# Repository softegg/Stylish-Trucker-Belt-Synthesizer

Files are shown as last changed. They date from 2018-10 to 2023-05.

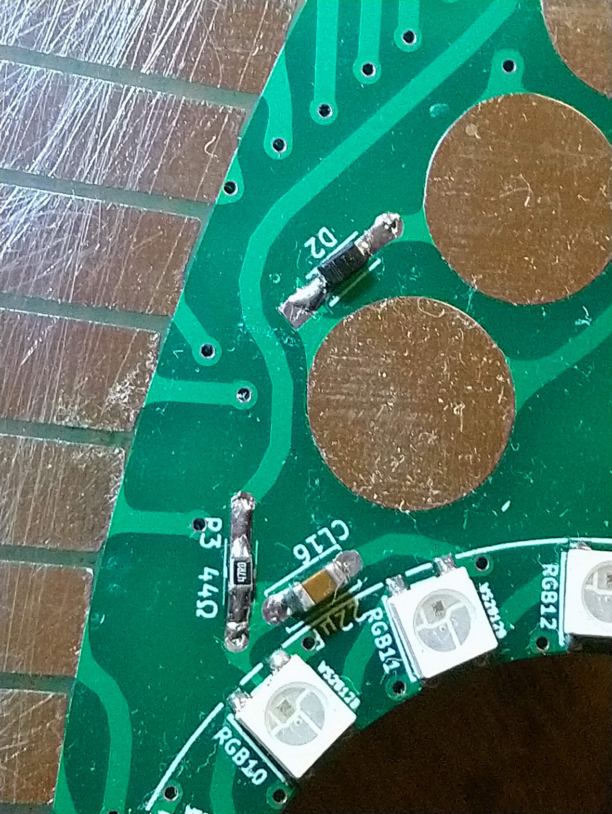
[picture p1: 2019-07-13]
photos/Stylish V4 PCB Assembled LED ring RC + diode detail front.jpg

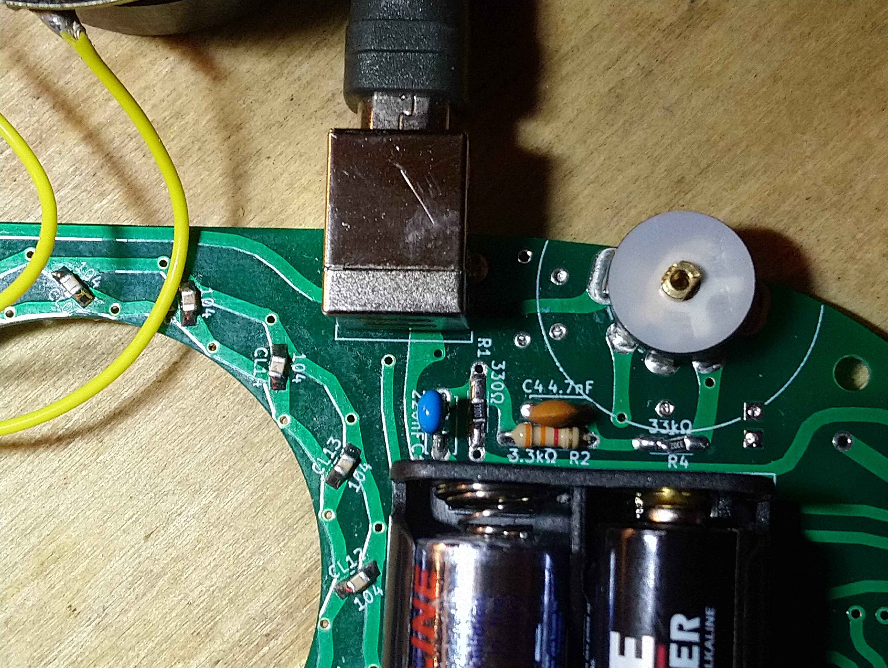
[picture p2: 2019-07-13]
photos/Stylish V4 PCB Assembled Power + PWM detail back.jpg

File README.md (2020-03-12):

# Stylish-Trucker-Belt-Synthesizer
A stylus-based music synthesizer you can wear as a belt! 

Conceived as a piece of premium swag for the MAGwest convention, "Stylish!" investigates how cheaply one can make a real, useful monophonic, digital (virtual analog) music synthesizer! Borrowing the stylus-based keyboard from the venerable Stylophone, and adding complete synthesis features like multiple oscillators, filters, envelopes, vibrato, etc. that are fully adjustable so that you can make your own sounds! It may even end up with a step sequencer and drum loop! 
Let's bring real music synthesis to the masses, stylishly!

Project is based around the "Blue Pill" STM32F103C8T6 microcontroller board that can be obtained from AliExpress for less than $2.

Code is written using Arduino IDE and STM32Duino.

Audio output is via PWM (10k resistor + 1uF capacitor) using the Mozzi library. CC4.0 Share Alike Non-commercial license applies.

LEDs are WS2812B, and the project PCB includes a header to use a standard 16 LED ring.

Amplifier is XH-M125 based on the XPT8871, which you an also buy cheaply from AliExpress. Headers are included to simply mount this board on the unit if you don't want to solder all of those parts.

Speaker is 40-50mm 0.5W 8 Ohm

<br />This work is licensed under a <a rel="license" href="http://creativecommons.org/licenses/by-nc-sa/4.0/">Creative Commons Attribution-NonCommercial-ShareAlike 4.0 International License</a>.

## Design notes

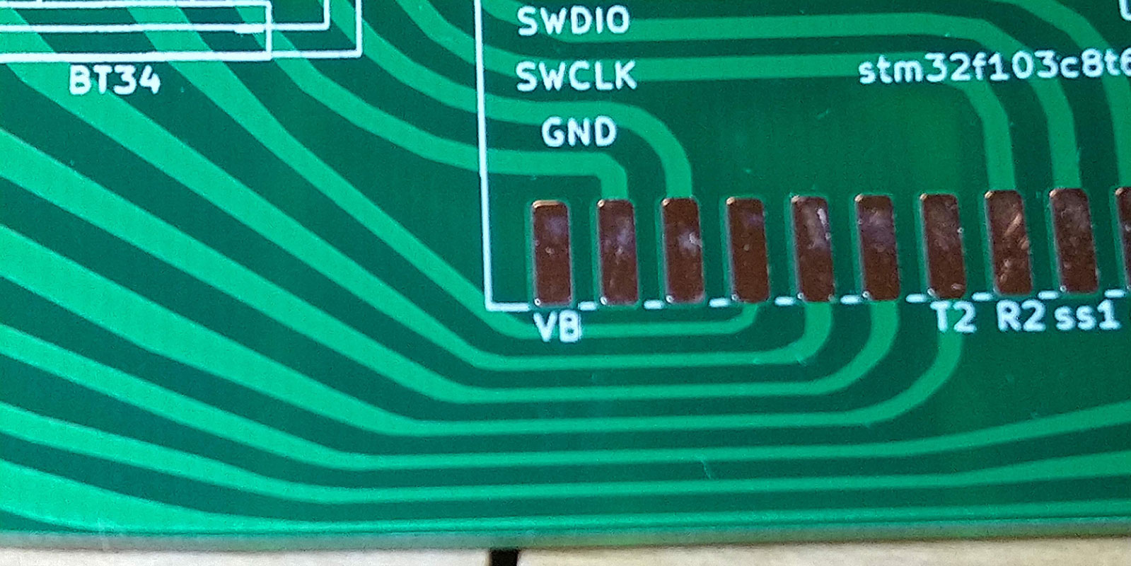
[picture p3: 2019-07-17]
photos/Thin-Trace-2.jpg

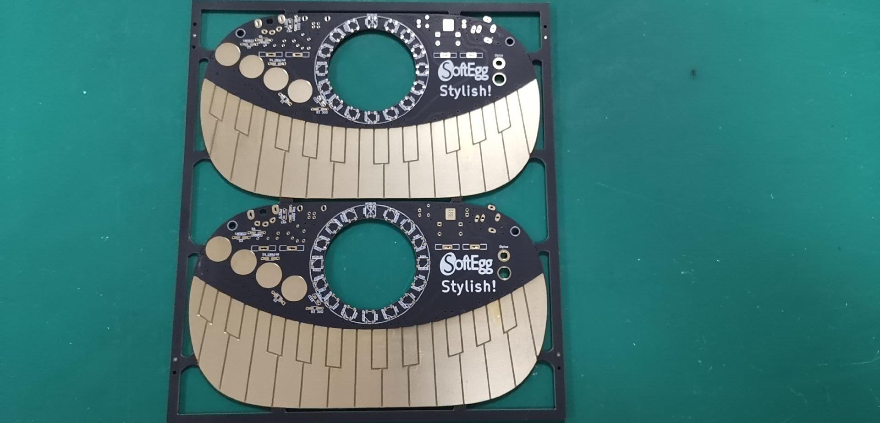
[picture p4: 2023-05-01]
photos/PCBs from Ai Green 1.jpg

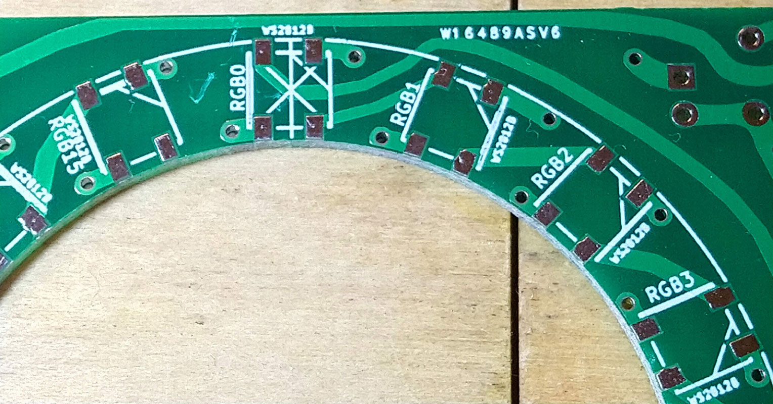
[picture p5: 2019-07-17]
photos/Thin-Trace-1.jpg

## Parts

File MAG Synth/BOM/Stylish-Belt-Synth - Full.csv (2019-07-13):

Stylish! Trucker Belt Buckle Synthesizer
Version 4.1
Bill of Materials
Designator | Package | Quantity | Designation | Supplier and ref | Notes | Changed
R4 | SMD 0805 | 1 | 33k? | https://www.aliexpress.com/item/32668040347.html
C4 | SMD 0805 | 1 | 4.7nF 472 | https://www.aliexpress.com/item/32964553793.html
CL16 | SMD 0805 | 1 | 22µF 226 | https://www.aliexpress.com/item/32964553793.html
RV1 | Wheel_Pot_W_Switch_RV12_B103_FUSTAR | 1 | Volume | https://www.aliexpress.com/item/32998159760.html | 10k? volume wheel potentiometer
BT34H1, BT12H1 | BatteryHolder_Keystone_2462_2xAA_MOD | 2 | Battery | https://www.aliexpress.com/item/32858688098.html
CA2, CA3 | SMD 0805 | 1 | 1?F 105 | https://www.aliexpress.com/item/32964553793.html
CA1 | CP_Radial_Tantal_D4.5mm_P2.50mm | 1 | 220?F
D1, D2 | SMD 0805 SOD-123 | 2 | 1N4148 | https://www.aliexpress.com/item/32897041428.html | Select 1n4148 SOD-123 See line on silk screen or arrow in copper for orientation.
D3, D4 | SMD 0805 | 2 | 1N5822 | https://www.aliexpress.com/item/32854160797.html | Select 1n5822 SS34. See line on silk screen or arrow in copper for orientation.
J1 | Stereo_Jack_3.5mm_Switch_Ledino_KB3SPRS | 1 | Headphone | https://www.aliexpress.com/item/32801912481.html
RGB0, RGB11, RGB12, RGB13, RGB14, RGB15, RGB9, RGB8, RGB7, RGB6, RGB10, RGB4, RGB3, RGB2, RGB1, RGB5 | WS2812B | 16 | WS2812B | https://www.aliexpress.com/item/32776703442.html | Very heat sensitive. Please follow heating profile on datasheet: http://www.world-semi.com/DownLoadFile/108
RA1 | SMD 0805 | 1 | 100? | https://www.aliexpress.com/item/32865947306.html
C3 | CP_Radial_D10.0mm_P5.00mm | 1 | 470?F | https://www.aliexpress.com/item/32676146418.html | Electrolytic thru hole capacitor
C2 | CP_Radial_D10.0mm_P5.00mm | 1 | 1000?F | https://www.aliexpress.com/item/1948624868.html | Electrolytic thru hole capacitor
LS1 | 4 Ohm 3W Loudspeaker 52MM | 1 | Speaker | https://www.aliexpress.com/item/32710566874.html | Speaker will mount in center hole. Leads should be long enough to reach and leave some slack. | July 12th, 2019
CA4 | SMD 0805 | 1 | 0.39?F 394 | https://www.aliexpress.com/item/32943505729.html
C1 | SMD 0805 | 1 | 220nF 224 | https://www.aliexpress.com/item/32998503996.html | Couldn’t find an 805, but 1206 will still fit.
CL15, CL14, CL13, CL12, CL11, CL10, CL9, CL8, CL7, CL6, CL5, CL4, CL3, CL2, CL1, CL0 | SMD805 | 16 | 0.1µF 104 | https://www.aliexpress.com/item/1115774532.html
R2 | SMD 0805 | 1 | 3.3k? | https://www.aliexpress.com/item/32865947306.html
R1 | SMD 0805 | 1 | 330? | https://www.aliexpress.com/item/32865947306.html
R3 | SMD 0805 | 1 | 30? | https://www.aliexpress.com/item/32865947306.html | Lowered to improve LED blue and green color. | July 13th, 2019
U1 | stm32f103c8t6-module-china-smd | 1 | stm32f103c8t6-module-china | https://www.aliexpress.com/item/STM32F103C8T6-ARM-STM32-Minimum-Development-Board-Module-for-arduino/32809970602.html | I implemented as 2 pin female pin headers and used the pinheaders that come with the controller.
U1 | Pin_Header_Angle_1x020_Pitch2.54mm_female | 2 | stm32f103c8t6-module-china | https://www.aliexpress.com/item/32733362388.html | Female pin headers for above. Be sure spacing is compatible when soldering.
U2 | SOIC-8-N | 1 | XPT8871 | https://www.aliexpress.com/item/50PCS-XPT8871-8871-SOP8/32918584881.html
J0 | USB_B | 1 | USB_B | https://www.aliexpress.com/item/539692317.html
Stylus | Stylus | 1 | Stylus | https://www.aliexpress.com/item/32959674689.html | Sold 2 per set, need 1 per unit.
Belt Clip | Belt Clip | 2 | Belt Clip | https://www.aliexpress.com/item/32991844720.html | Need these to attach to the case. Can we please ship these with the PCB order?

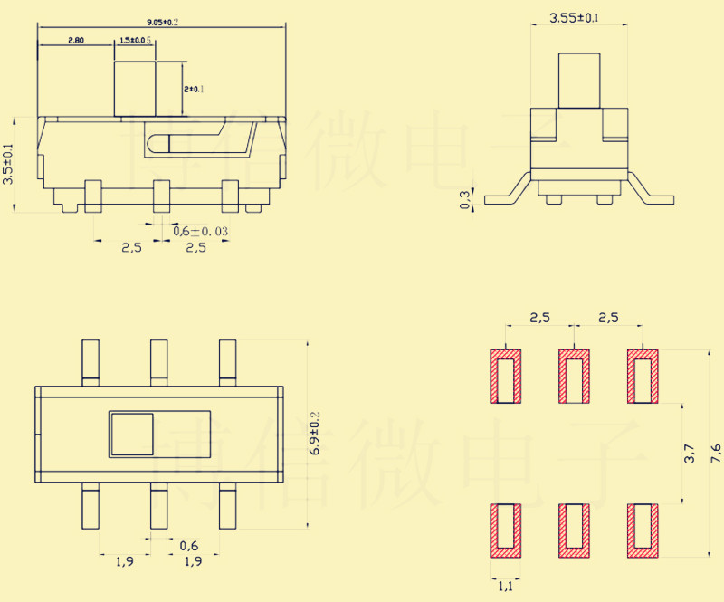
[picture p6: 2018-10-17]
3d models/Parts/MSS22D18.jpg

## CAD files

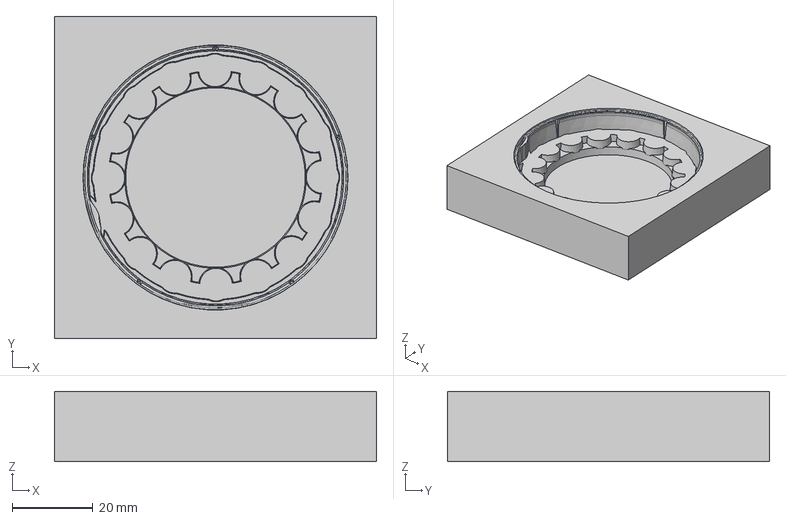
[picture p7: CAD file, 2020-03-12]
3d models/Mold/Negative/STEP/Stylish Belt Synth - LED Bezel - Outside Negative.step
80.0 x 80.0 x 17.5 mm

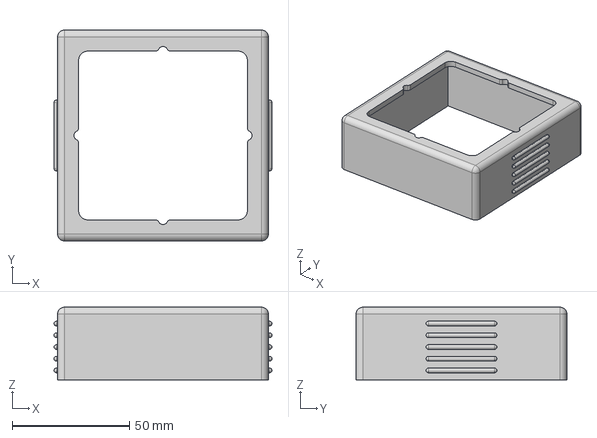
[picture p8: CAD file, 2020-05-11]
3d models/Mold/Positive - Mold Molds/STEP/Stylish Belt Synth - LED Bezel - Mold Walls.step
93.0 x 90.0 x 31.0 mm

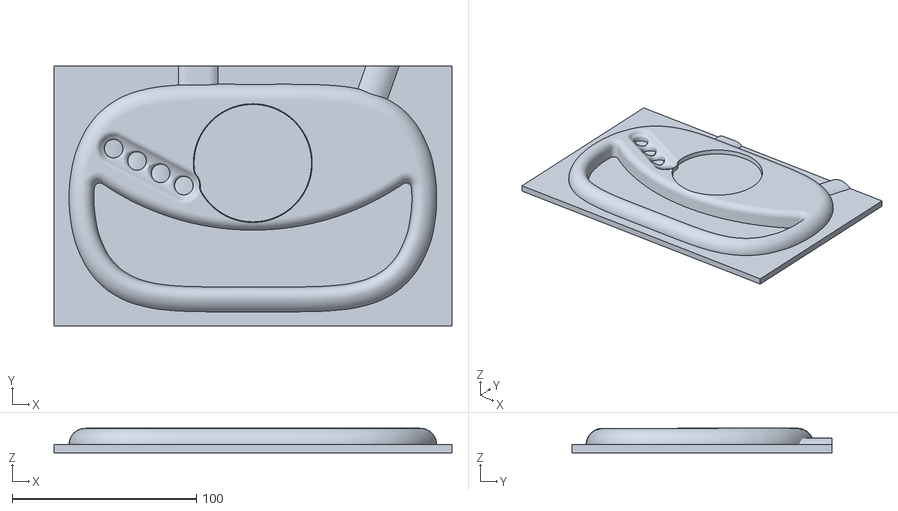
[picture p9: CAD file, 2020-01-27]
3d models/Mold/Positive - Mold Molds/STL/Stylish - Top - Outside Positive.stl
216.3 x 141.5 x 13.4

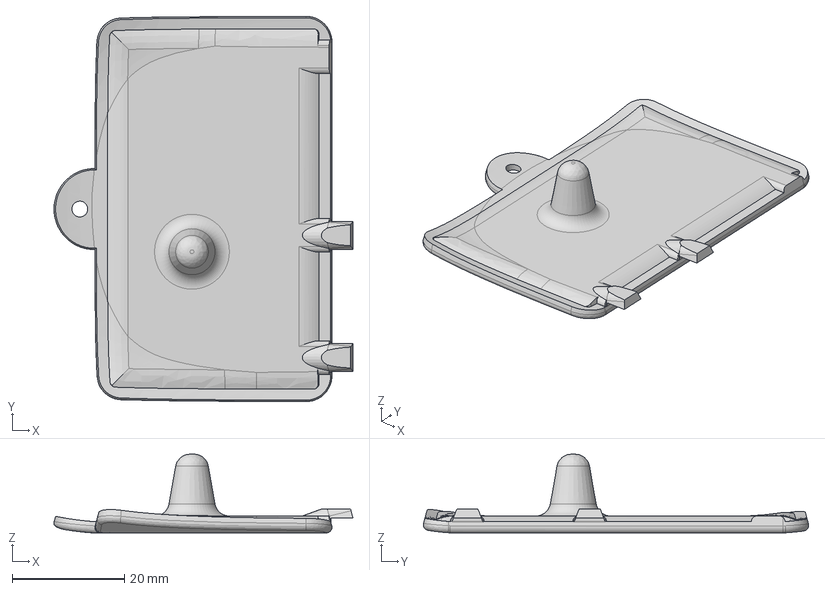
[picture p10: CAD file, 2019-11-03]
3d models/Normal Models/STEP/Stylish Belt Synth V4 Battery Door 2.step
53.2 x 68.5 x 14.0 mm

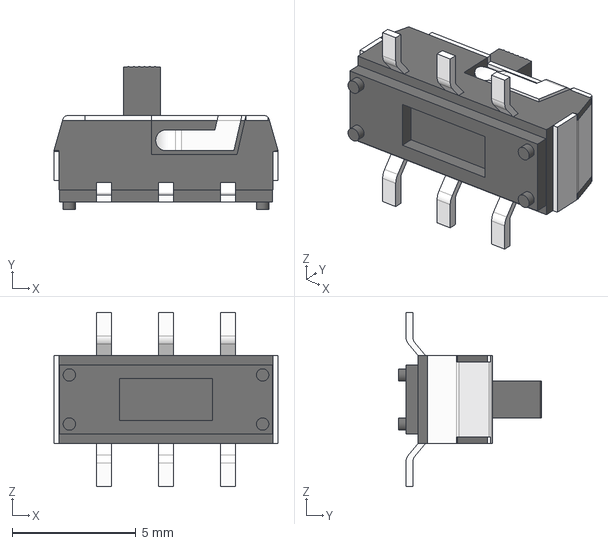
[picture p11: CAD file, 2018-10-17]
3d models/Parts/MSS22D18 Switch v3.step
9.05 x 5.79 x 7.05 mm

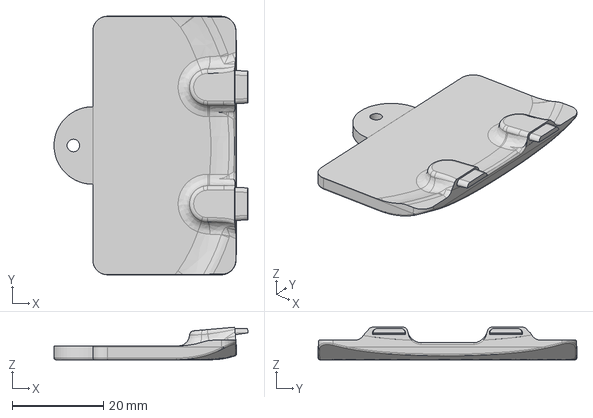
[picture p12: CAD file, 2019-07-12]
3d models/Stylish Belt Synth V2 Right Battery Door.step
42.5 x 56.7 x 7.16 mm

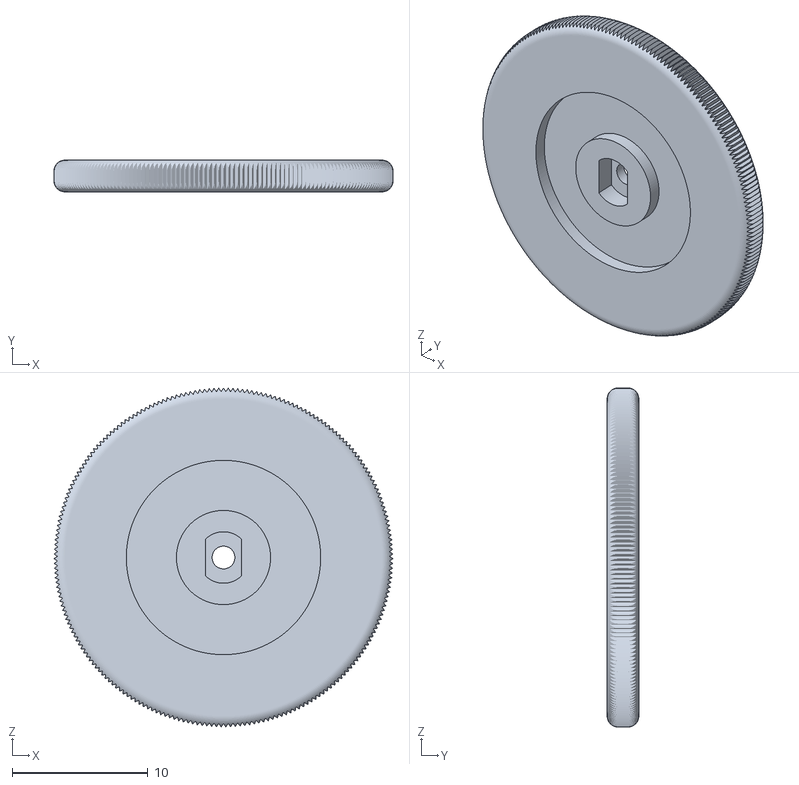
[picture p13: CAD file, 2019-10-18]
3d models/woodCNC/StylishVolumeWheelforWoodCNC (3d print this).stl
25.0 x 2.34 x 25.0

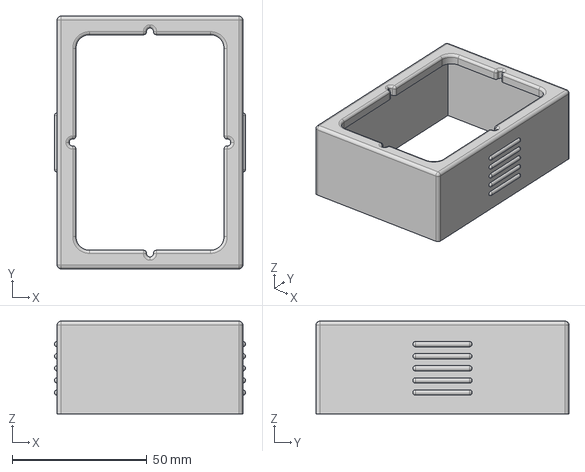
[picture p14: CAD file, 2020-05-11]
3d models/Mold/Positive - Mold Molds/STEP/Stylish Belt Synth - Battery Doors - Outside Positive Walls.step
71.0 x 94.0 x 34.5 mm

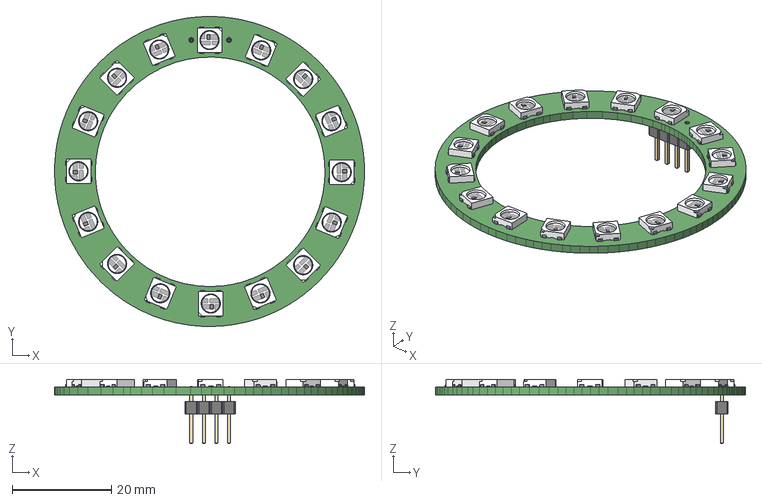
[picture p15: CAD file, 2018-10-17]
3d models/Parts/WS2812B-16_LED-RING-flip.step
62.6 x 62.6 x 13.0 mm

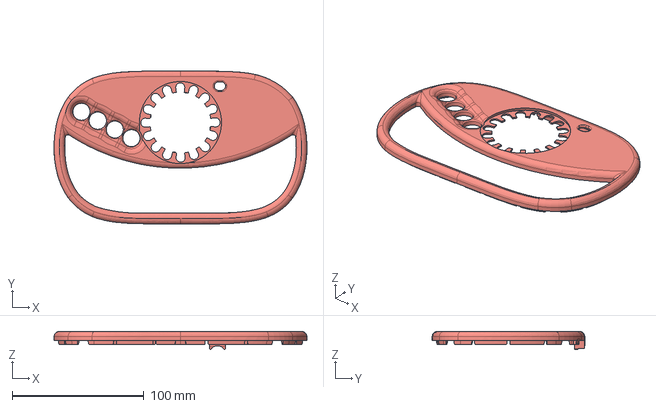
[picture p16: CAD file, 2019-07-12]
3d models/Stylish Belt Synth V2 Top.step
192.1 x 116.0 x 13.8 mm

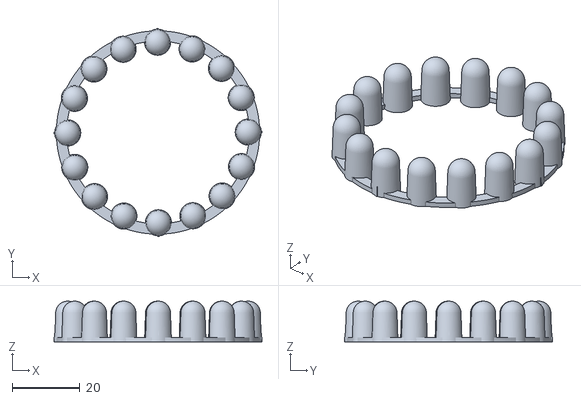
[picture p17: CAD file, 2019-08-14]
3d models/woodCNC/StylishLEDLightpipeForWoodCNC (3d print this).stl
61.3 x 61.3 x 12.0

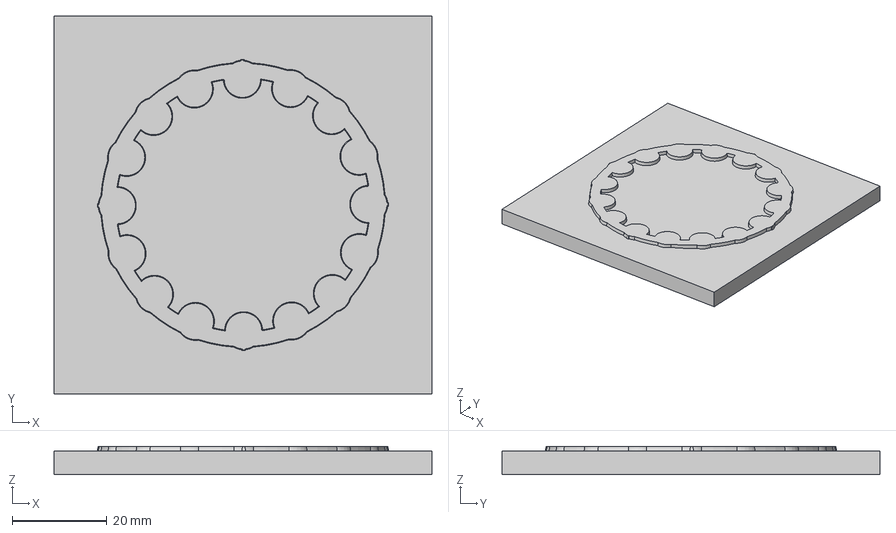
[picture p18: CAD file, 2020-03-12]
3d models/Mold/Negative/STEP/Stylish Belt Synth - LED Lightpipe - Inside Negative.step
80.0 x 80.0 x 6.00 mm
LED Bezel
LED Lightpipe

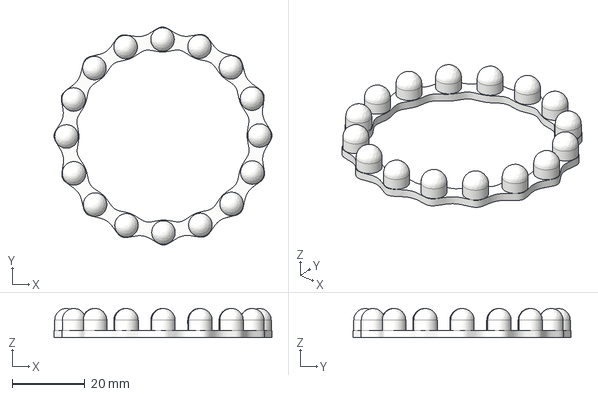
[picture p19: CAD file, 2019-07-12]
3d models/Stylish Belt Synth V2 LED Lightpipe.step
60.1 x 60.1 x 8.00 mm

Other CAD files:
3d models/Normal Models/STEP/Stylish Belt Synth V4 Battery Door 1.step
3d models/Normal Models/STEP/Stylish Belt Synth V4 LED Lightpipe.step
3d models/woodCNC/Stylish Volume Wheel (3d print).stl
3d models/Amp Cover.stl
3d models/Back.stl
3d models/Belt Clip.stl
3d models/Front v2.stl
3d models/Front.stl
3d models/LED Bezel Inner Translucent PLA.stl
3d models/LED Bezel Outer Black TPE.stl
3d models/Mold/Negative/STEP/Stylish Belt Synth - Battery Door 1 - Inside Negative.step
3d models/Mold/Negative/STEP/Stylish Belt Synth - Battery Door 1 - Outside Negative.step
3d models/Mold/Negative/STEP/Stylish Belt Synth - Battery Door 2 - Inside Negative.step
3d models/Mold/Negative/STEP/Stylish Belt Synth - Battery Door 2 - Outside Negative.step
3d models/Mold/Negative/STEP/Stylish Belt Synth - Bottom - Outside Negative.step
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

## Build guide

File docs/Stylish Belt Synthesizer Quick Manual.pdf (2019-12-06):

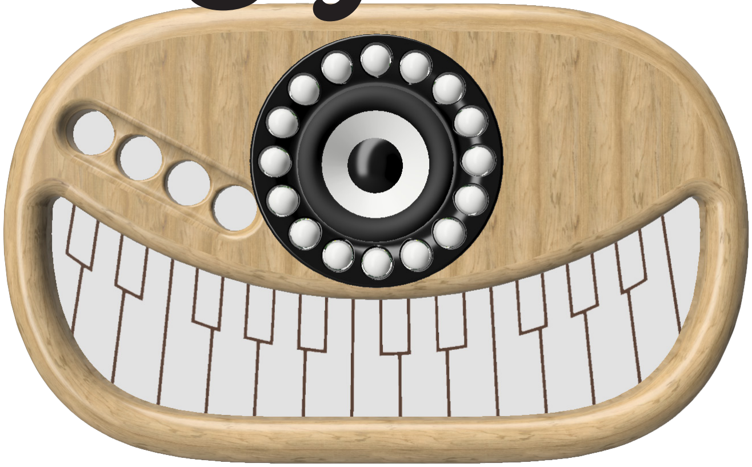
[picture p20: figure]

Trucker Belt-Buckle Synthesizer

## Care and feeding of your

# Stylish!

2

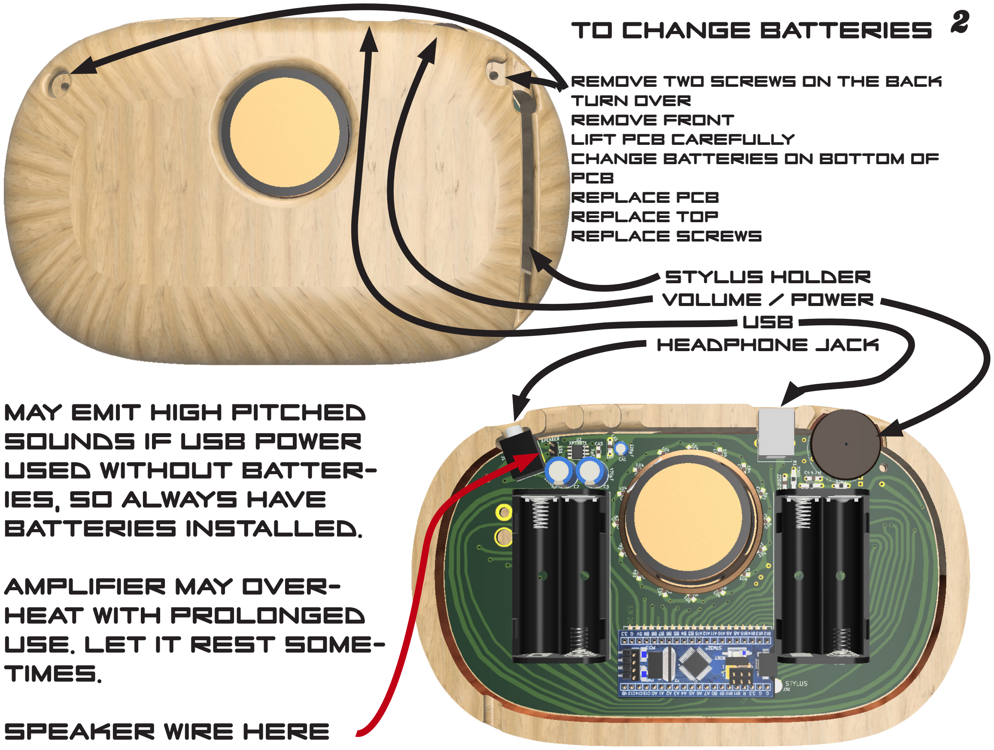
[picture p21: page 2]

MAY EMIT HIGH PITCHED
SOUNDS IF USB POWER
USED WITHOUT BATTER-IES, So ALWAYS HAVE
BATTERIES INSTALLED.

AMPLIFIER MAY OVER-HEAT WITH PROLONGED
USE. LET IT REST SOME-TIMES.

SPEAKER WIRE HERE

To CHANGE BATTERIES

REMOVE TWO SCREWS ON THE BACK TURN OVER
REMOVE FRONT
LIFT PCB CAREFULLY
CHANGE BATTERIES ON BOTTOM OF PCB
REPLACE PCB
REPLACE TOP
REPLACE SCREWS
STYLUS HOLDER
VOLUME / POWER
USB
HEADPHONE JACK

# CONTROLS

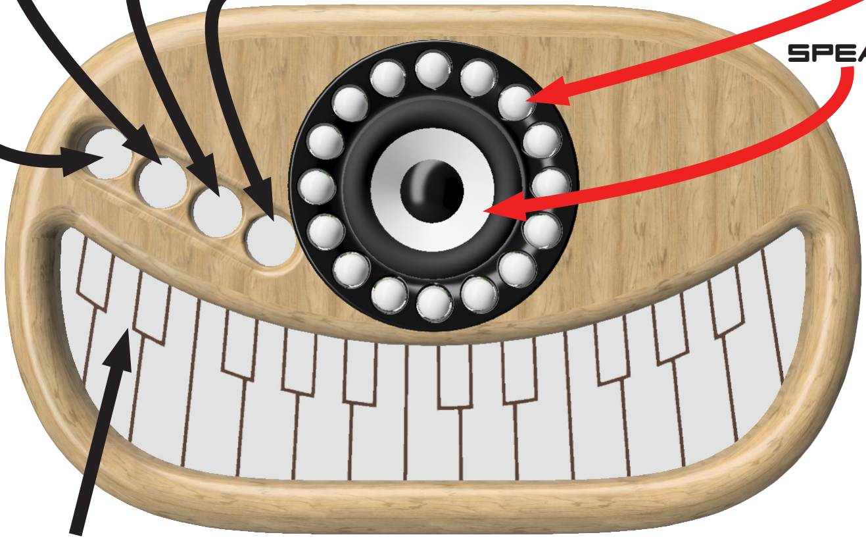
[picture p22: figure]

KEYBOARD / PARAMATER SELECT / PARAMETER VALUE

SPEAKER

INDICATOR LED RING
System Paramter Edit

Parameter Edit

Patch Write

Patch Select

3

Patch Select - LOAD A SOUND TO PLAY ON THE KEYBOARD Tap once and LED RING FLASHES BLUE TAP ON KEYBOARD To SELECT A SOUND TO LOAD.
NEW SOUND WILL PLAY
TAP TIL YOU FIND THE SOUND YOU WANT TO LOAD.
TAP “PATCH SELECT” AGAIN TO KEEP SOUND YOU CAN PLAY IT ON THE KEYBOARD NOW TAP anY other button to abort
(WILL RETURN TO ORIGINAL SOUND)
PATCH WRITE - | WRITE THE SOUND TO A DIFFERENT SLOT
| TAP ONCE AND LED RING FLASHES RED
| TAP ON KEYBOARD TO SELECT A SOUND
| TO OVERWRITE
| SOUND IN SELECTED SLOT WILL PLAY
| TAP TIL YOU FIND THE SOUND YOU WANT
| TO OVERWRITE
| TAP “PATCH WRITE” AGAIN TO OVERWRITE SOUND
| YOU CAN PLAY IT ON THE KEYBOARD NOW
| TAP anY other button to abort
| (WILL RETURN TO ORIGINAL SOUND)
CONTROLS | 4

PARAMETER - CHANGE SYNTHESIZER PARAMETER
EDIT | Tap once and LED RING FLASHES GREEN ON THE LEFT SIDE ONLY TAP ON KEYBOARD To SELECT A PARAMETER TO EDIT LED RING WILL ALTERNATE BETWEEN RIGHT HALF GREEN PARAMETER NUMBER BARGRAPH AND PARAMETER VALUE BARGRAPH TAP ON KEYBOARD TO SELECT A NEW VALUE PARAMETER VALUE WILL UPDATE (BARGRAPH WILL REFLECT THIS) SOUND WILL PLAY TAP “Parameter Edit” AGAIN TO KEEP CHANGE YOU CAN PLAY ON THE KEYBOARD NOW TAP anY other button to abort (WILL RETURN TO ORIGINAL SOUND)

PARAMETER LIST ON NEXT PAGE

# CONTROLS

5

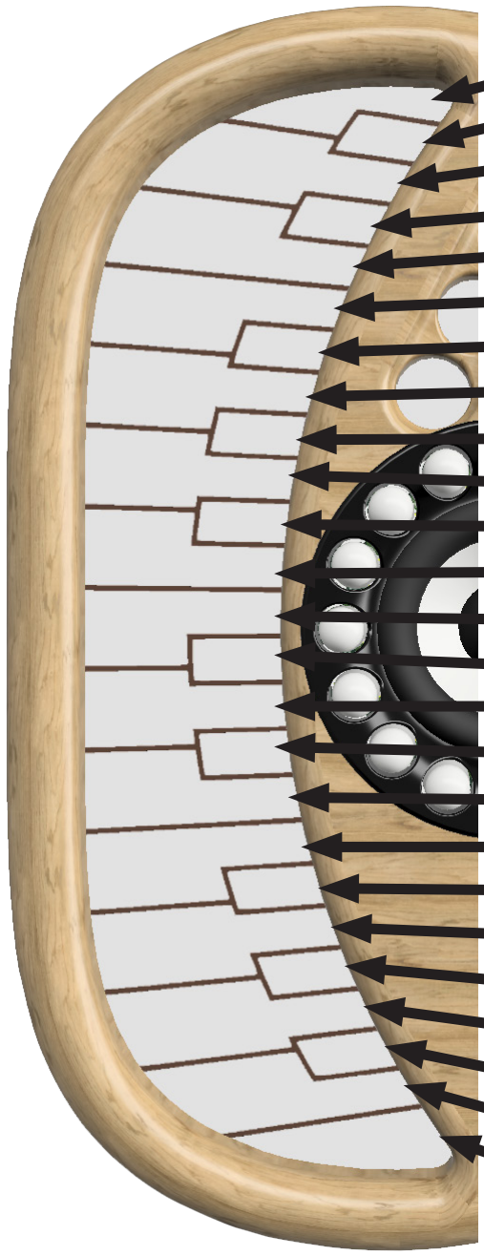
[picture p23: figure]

# PARAMETER EDIT

OSCILLATOR 1 WAVEFORM
OSCILLATOR 1 NOTE OFFSET
OSCILLATOR 2 WAVEFORM
OSCILLATOR 2 NOTE OFFSET
NOISE LEVEL
OSCILLATOR DETUNE
ENVELOPE ATTACK
ENVELOPE DECAY
ENVELOPE SUSTAIN
ENVELOPE RELEASE
FILTER RESONANCE
FILTER FREQUENCY
LFO WAVEFORM
LFO FREQUENCY
*FUTURE*
*FUTURE*
ENVELOPE TO FILTER
ENVELOPE TO PITCH
*FUTURE*
*FUTURE*
LFO TO FILTER
LFO TO PITCH
LFO TO VOLUME
*FUTURE*
LFO TO NOISE

6

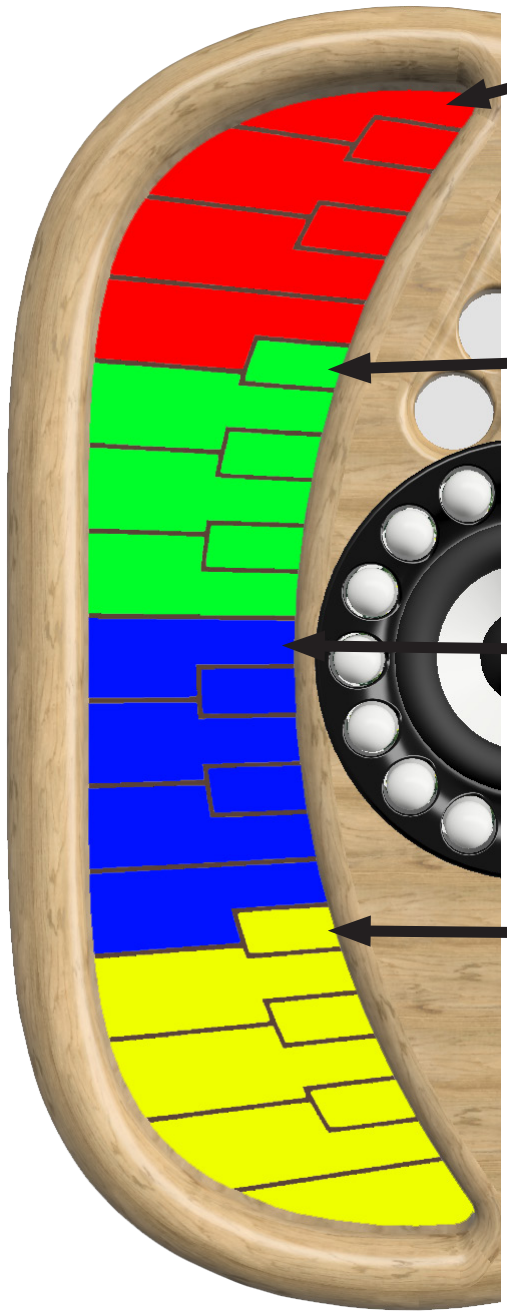
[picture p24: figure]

SAWTOOTH WAVE : OCTAVE 1
OCTAVE 2
OCTAVE 3
OCTAVE 4
OCTAVE 5
OCTAVE 6
SQUARE WAVE : | OCTAVE 1
| OCTAVE 2
| OCTAVE 3
| OCTAVE 4
| OCTAVE 5
| OCTAVE 6
TRIANGLE WAVE : OCTAVE 1
| OCTAVE 2
| OCTAVE 3
| OCTAVE 4
| OCTAVE 5
| OCTAVE 6
SINE WAVE : | OCTAVE 1
| OCTAVE 2
| OCTAVE 3
| OCTAVE 4
| OCTAVE 5
| OCTAVE 6
LFO WAVEFORM IS THE SAME BUT NO OCTAVE

# OSCILLATOR 1,2

# WAVEFORM

7

SYSTEM | - CHANGE GLOBAL PARAMETER
PARAMETER | Tap once and LED RING FLASHES YELLOW
EDIT | ON THE LEFT SIDE ONLY
| TAP ON KEYBOARD To SELECT A PARAMETER
| TO EDIT
| LED RING WILL ALTERNATE BETWEEN
| RIGHT HALF YELLOW
| SYSTEM PARAMETER NUMBER BARGRAPH
| AND PARAMETER VALUE BARGRAPH
| TAP ON KEYBOARD TO SELECT A NEW VALUE
| SYSTEM PARAMETER VALUE WILL UPDATE
| (BARGRAPH WILL REFLECT THIS)
| SOUND WILL PLAY
| TAP “SYSTEM Parameter Edit” AGAIN TO KEEP
| YOU CAN PLAY ON THE KEYBOARD NOW
| TAP anY other button to abort
| (WILL RETURN TO ORIGINAL VALUE)

PARAMETER LIST ON NEXT PAGE.

CONTROLS | 8

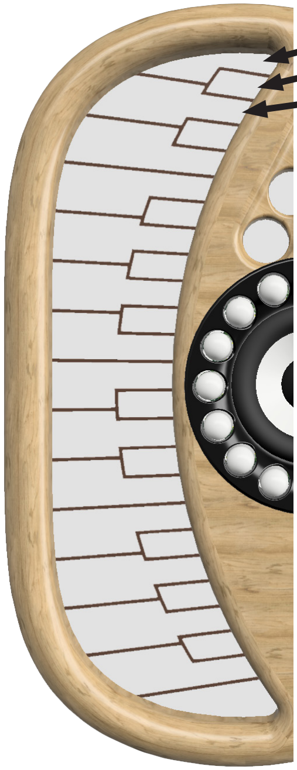
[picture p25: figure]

# SYSTEM

# PARAMETERS

LED BRIGHTNESS
CoARSE TUNING (NOTE)
FINE TUNING (2 CENTS)
*FUTURE* ...

9

EACH WOOD STYLISH! UNIT IS a hand-assembled DIY creation! Each unit is unique and will have character and eccentricities due to the nature of the wood, and the trials of construction.
Please Appreciate these as beauty marks!
The 3D printed parts will melt if exposed to heat!
Do not leave STYLISH! in your hot car, in the direct sun, or in other hot places!
Stylish! is made of WOOD!
* Although it is covered in a polyurethane varnish, it is probably not good to expose it to moisture!
* SCREWS CAN BE STRIPPED OUT IF YOU ARE NOT CAREFUL! PLEASE TAKE CARE NOT TO OVER-TIGHTEN SCREWS!
* WOOD IS SOFT AND CAN DENT and SCRATCH EASILY! TAKE CARE NOT TO LET STYLISH GET SCRATCHED or DENTED! The STYLUS wire is somewhat delicate! Please take care not to rip the wire out!
Take care when changing batteries to align screws with the HOLES IN THE PCB when putting it back together so as not to scratch the PCB.

# CARE INSTRUCTIONS 10

# SCHEMATIC DIAGRAM

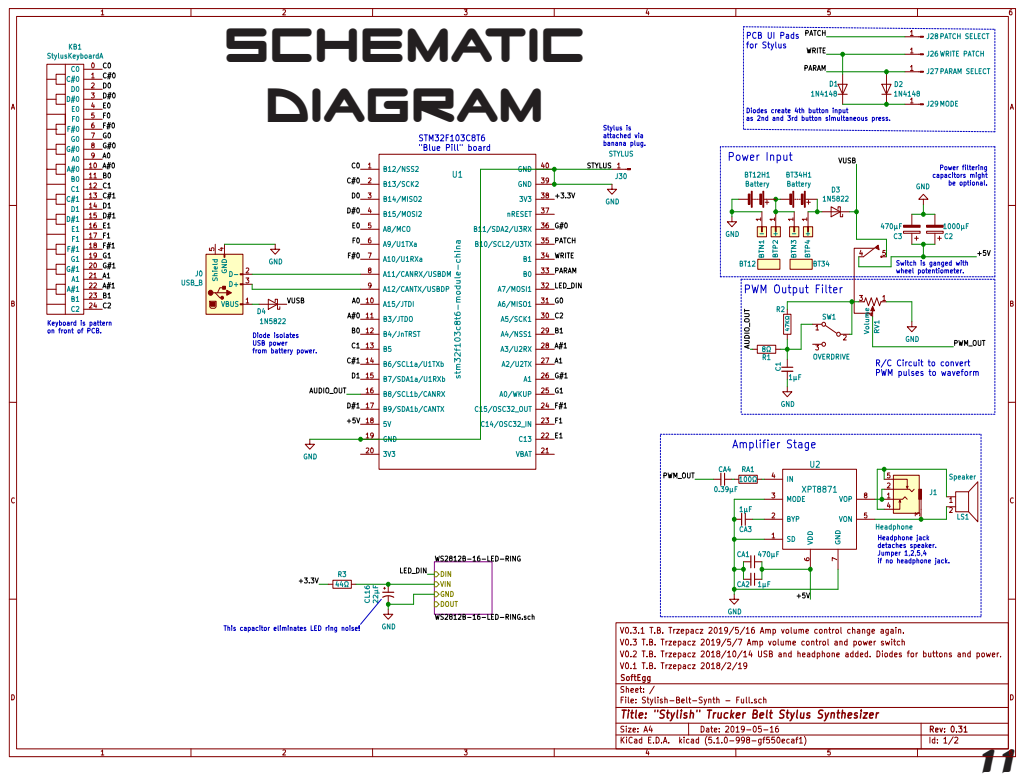
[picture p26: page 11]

®

12

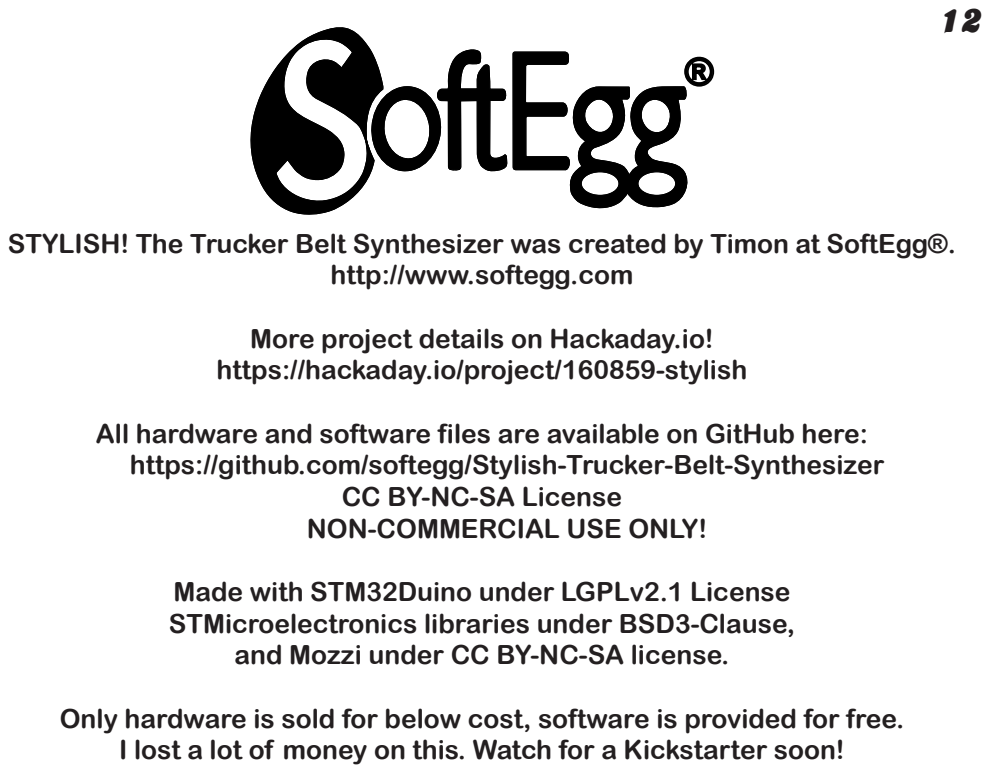
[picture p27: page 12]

STYLISH! The Trucker Belt Synthesizer was created by Timon at SoftEgg®.

http://www.softegg.com

More project details on Hackaday.io!
https://hackaday.io/project/160859-stylish

All hardware and software files are available on GitHub here:
https://github.com/softegg/Stylish-Trucker-Belt-Synthesizer

CC BY-NC-SA License
NON-COMMERCIAL USE ONLY!

Made with STM32Duino under LGPLv2.1 License
STMicroelectronics libraries under BSD3-Clause,
and Mozzi under CC BY-NC-SA license.

Only hardware is sold for below cost, software is provided for free.
I lost a lot of money on this. Watch for a Kickstarter soon!

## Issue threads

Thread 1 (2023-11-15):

KiCAD schematic does not have the cache file

blu006, 2023-11-15:
This issue is raised with https://github.com/softegg/Stylish-Trucker-Belt-Synthesizer/blob/0fc1f83537cc46e5045114e1b37d2316abffe41a/MAG%20Synth/Stylish-Belt-Synth%20-%20Full.sch

On trying to open the kicad schematic file, the following message shows up.

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

With the schematic file open, many symbols are missing.
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

It is recommended that the ...cache.lib file is uploaded.

softegg, 2023-11-15:
Oopsie!
I added the cache.lib file that it asked for.
It's so hard to tell which files are necessary and which are cruft...
Please let me know if there are any further difficulties!

blu006, 2023-11-16:
Were the project files for `Stylish-Belt-Synth - Full` renamed?

The file in commit ebaa3cd6d5b41de6f620a7fdb4b774d3655a4098 is named `Stylish-Belt-Synth-cache.lib`, not the necessary `Stylish-Belt-Synth -Full-cache.lib`.

softegg, 2023-11-16:
Oh, it wanted that one.
It's in now.
I think I copied it by exporting the project, but I really don't remember.
It became "full" for disambiguation when I started making split versions so that it could be cut in two parts on my PCB mill for prototyping.
Git confuses me.

blu006, 2023-11-16:
you can write that in a readme file in the `MAG Synth` folder.

Closed 2023-11-16.

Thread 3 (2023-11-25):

Out of tune

MichaelJuan, 2023-11-25:
Default scale  when powered on is offset by 4 scale steps. one of the notes is just wrong even with the offset. It should be F but its F#.

softegg, 2023-11-25:
I believe I fixed the offset issue on release at MAGwest.
Have you tried it with the latest firmware?

MichaelJuan, 2023-11-25:
Ok will updtae maglab synth later.

Closed 2023-11-25.

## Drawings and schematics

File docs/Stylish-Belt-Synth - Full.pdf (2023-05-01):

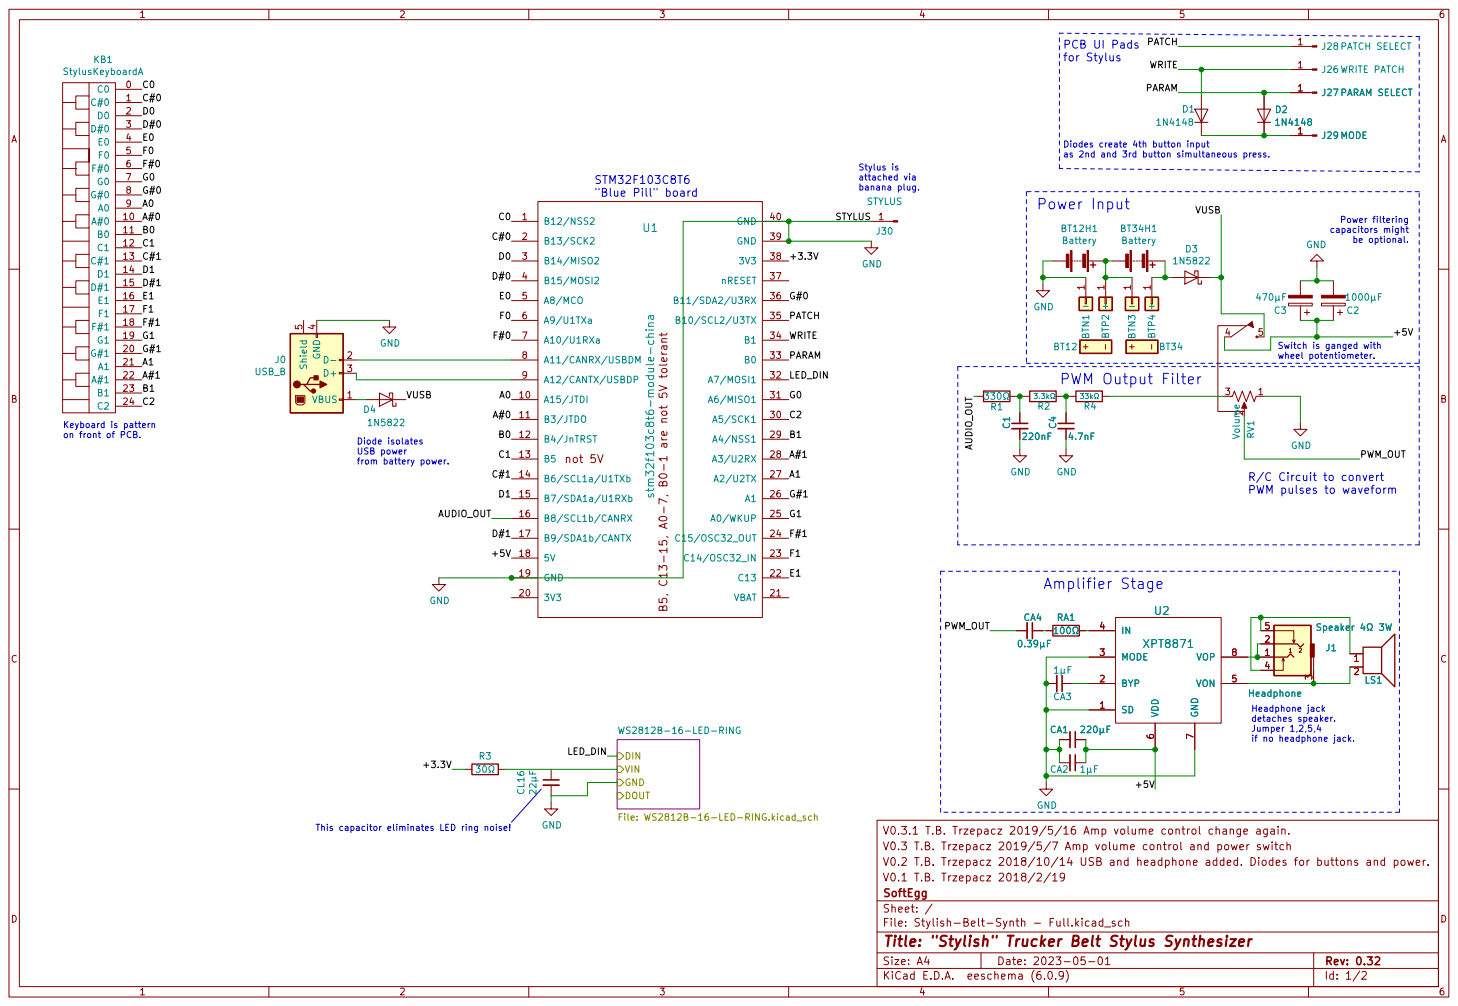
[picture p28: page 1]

PWM_OUT PATCH
if no headphone jack. Switch is ganged with wheel potentiometer. Power filtering

for Stylus Diodes create 4th button input as 2nd and 3rd button simultaneous press. Diode isolates USB power

1N4148 GND GND B5, C13-15, A0-7, B0-1 are not 5V tolerant not 5V

Stylus is attached via

"Blue Pill" board
from battery power. This capacitor eliminates LED ring noise!

R/C Circuit to convert
PWM pulses to waveform

Headphone jack detaches speaker. Jumper 1,2,5,4

DOUT GND WS2812B-16-LED-RING

V0.3.1 T.B. Trzepacz 2019/5/16 Amp volume control change again. DIN
VIN

V0.3 T.B. Trzepacz 2019/5/7 Amp volume control and power switch
V0.2 T.B. Trzepacz 2018/10/14 USB and headphone added. Diodes for buttons and power.
V0.1 T.B. Trzepacz 2018/2/19
File: Stylish-Belt-Synth - Full.kicad_sch Sheet: / SoftEgg

Id: 1/2 Title: "Stylish" Trucker Belt Stylus Synthesizer

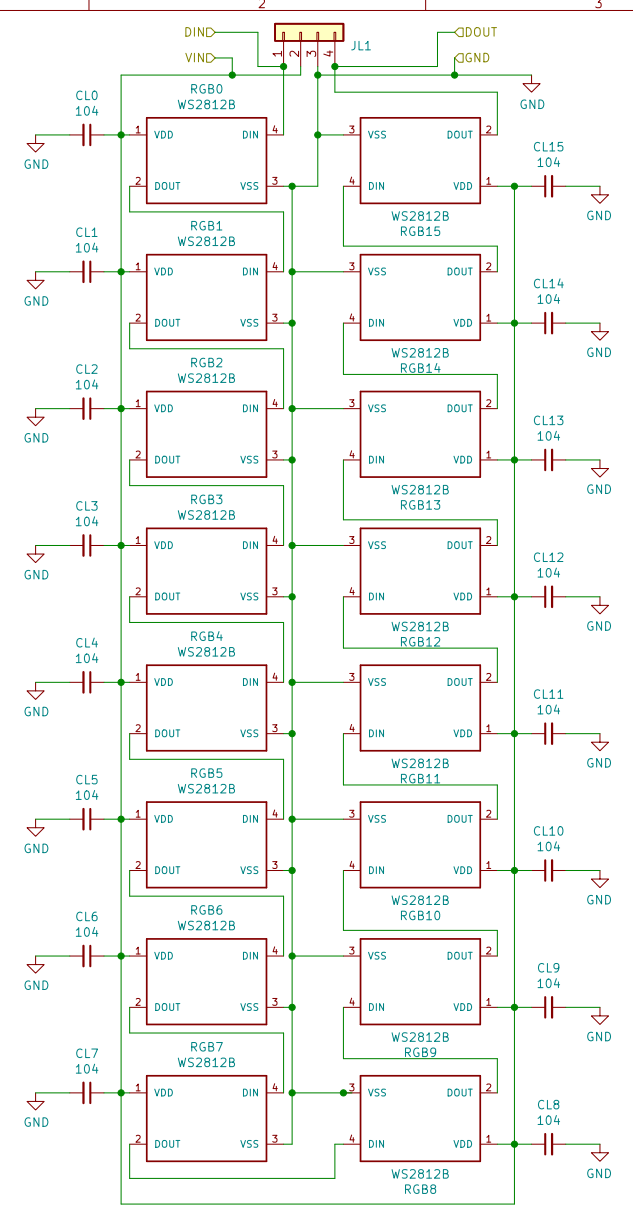
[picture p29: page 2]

V0.3 T.B Trzepacz 2019/5/7
V0.2 T.B. Trzepacz 2018/10/14
V0.1 T.B. Trzepacz 2018/2/19
File: WS2812B-16-LED-RING.kicad_sch Sheet: /WS2812B-16-LED-RING/ SoftEgg

Id: 2/2 Title: "Stylish" Trucker Belt Stylus Synthesizer

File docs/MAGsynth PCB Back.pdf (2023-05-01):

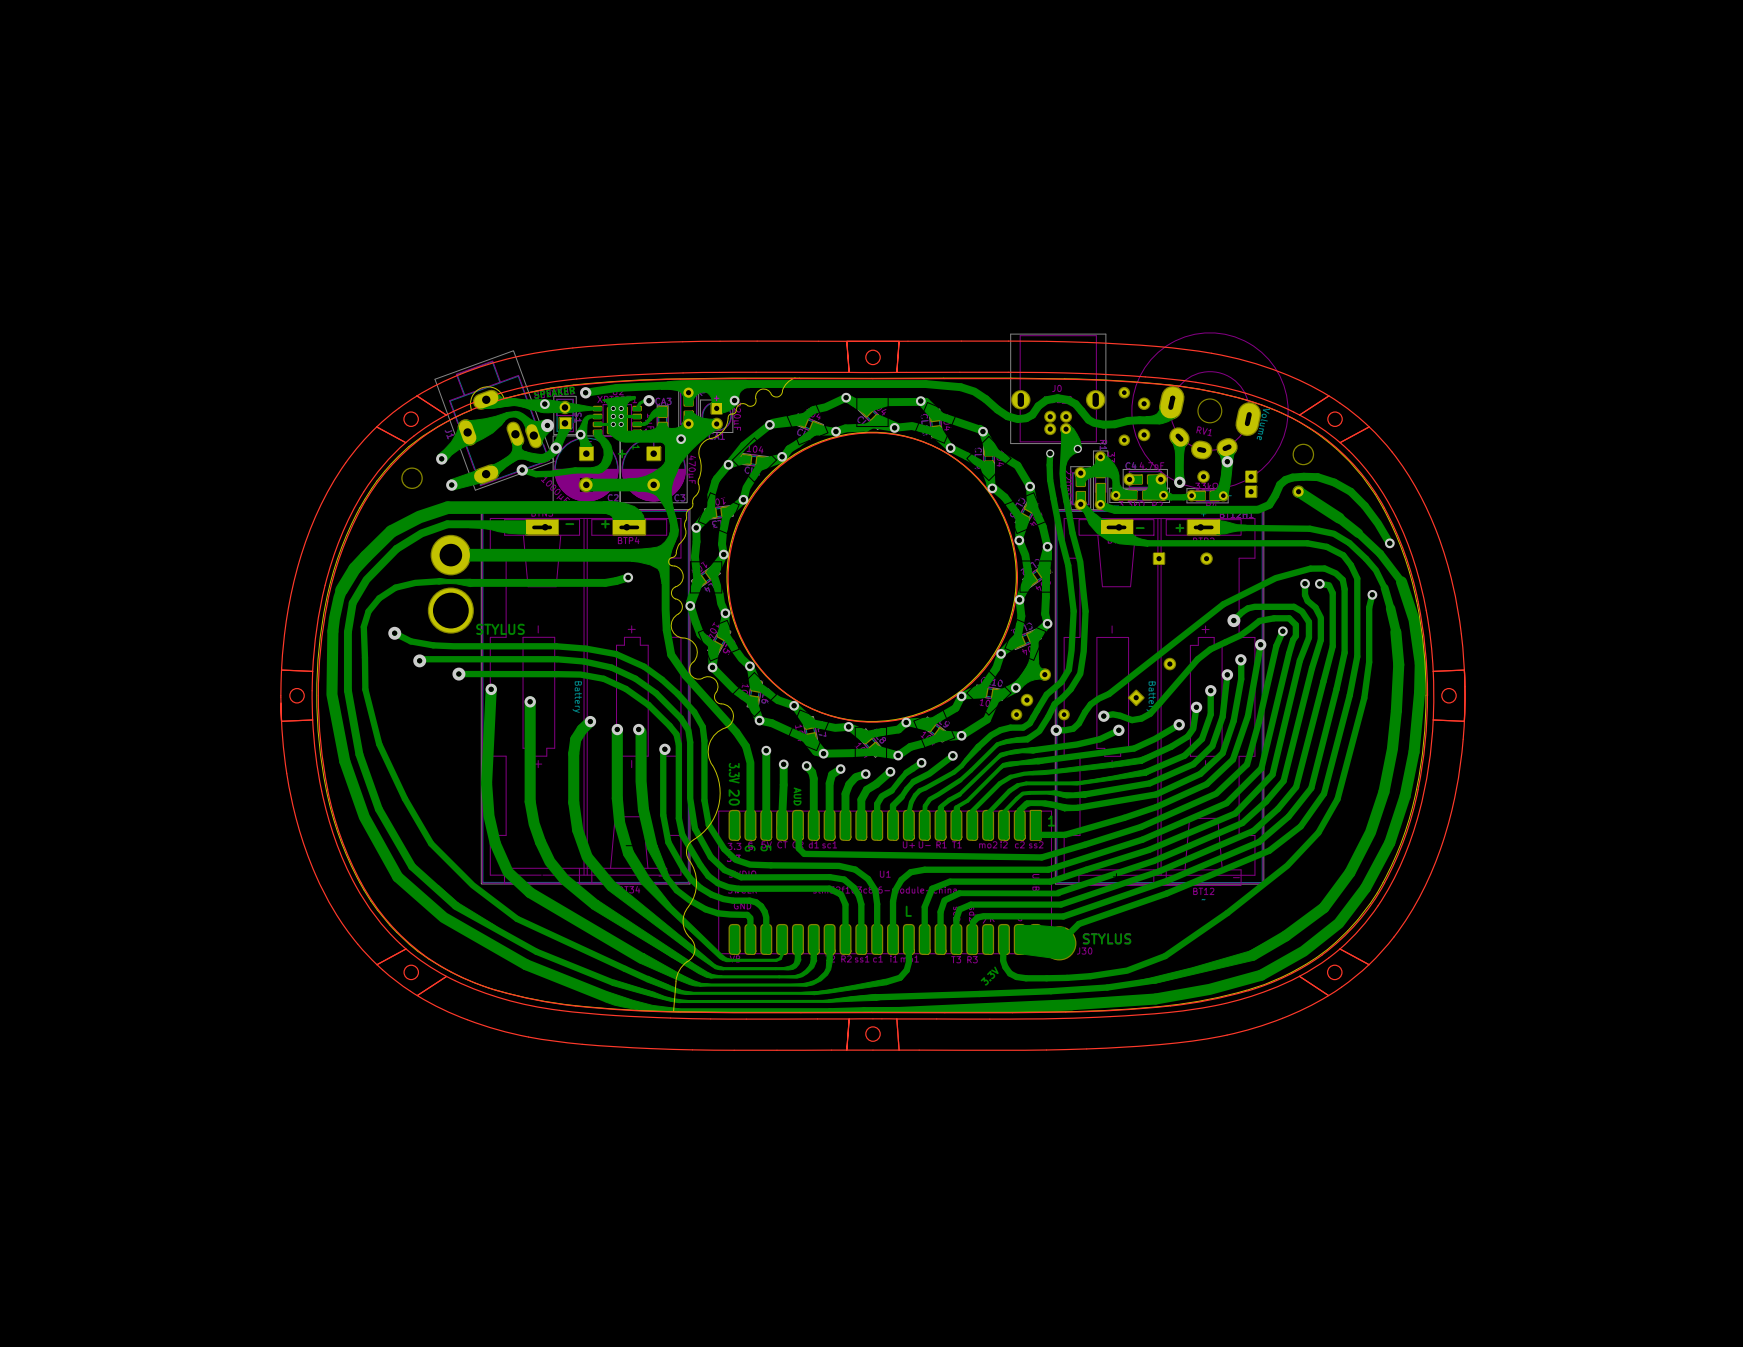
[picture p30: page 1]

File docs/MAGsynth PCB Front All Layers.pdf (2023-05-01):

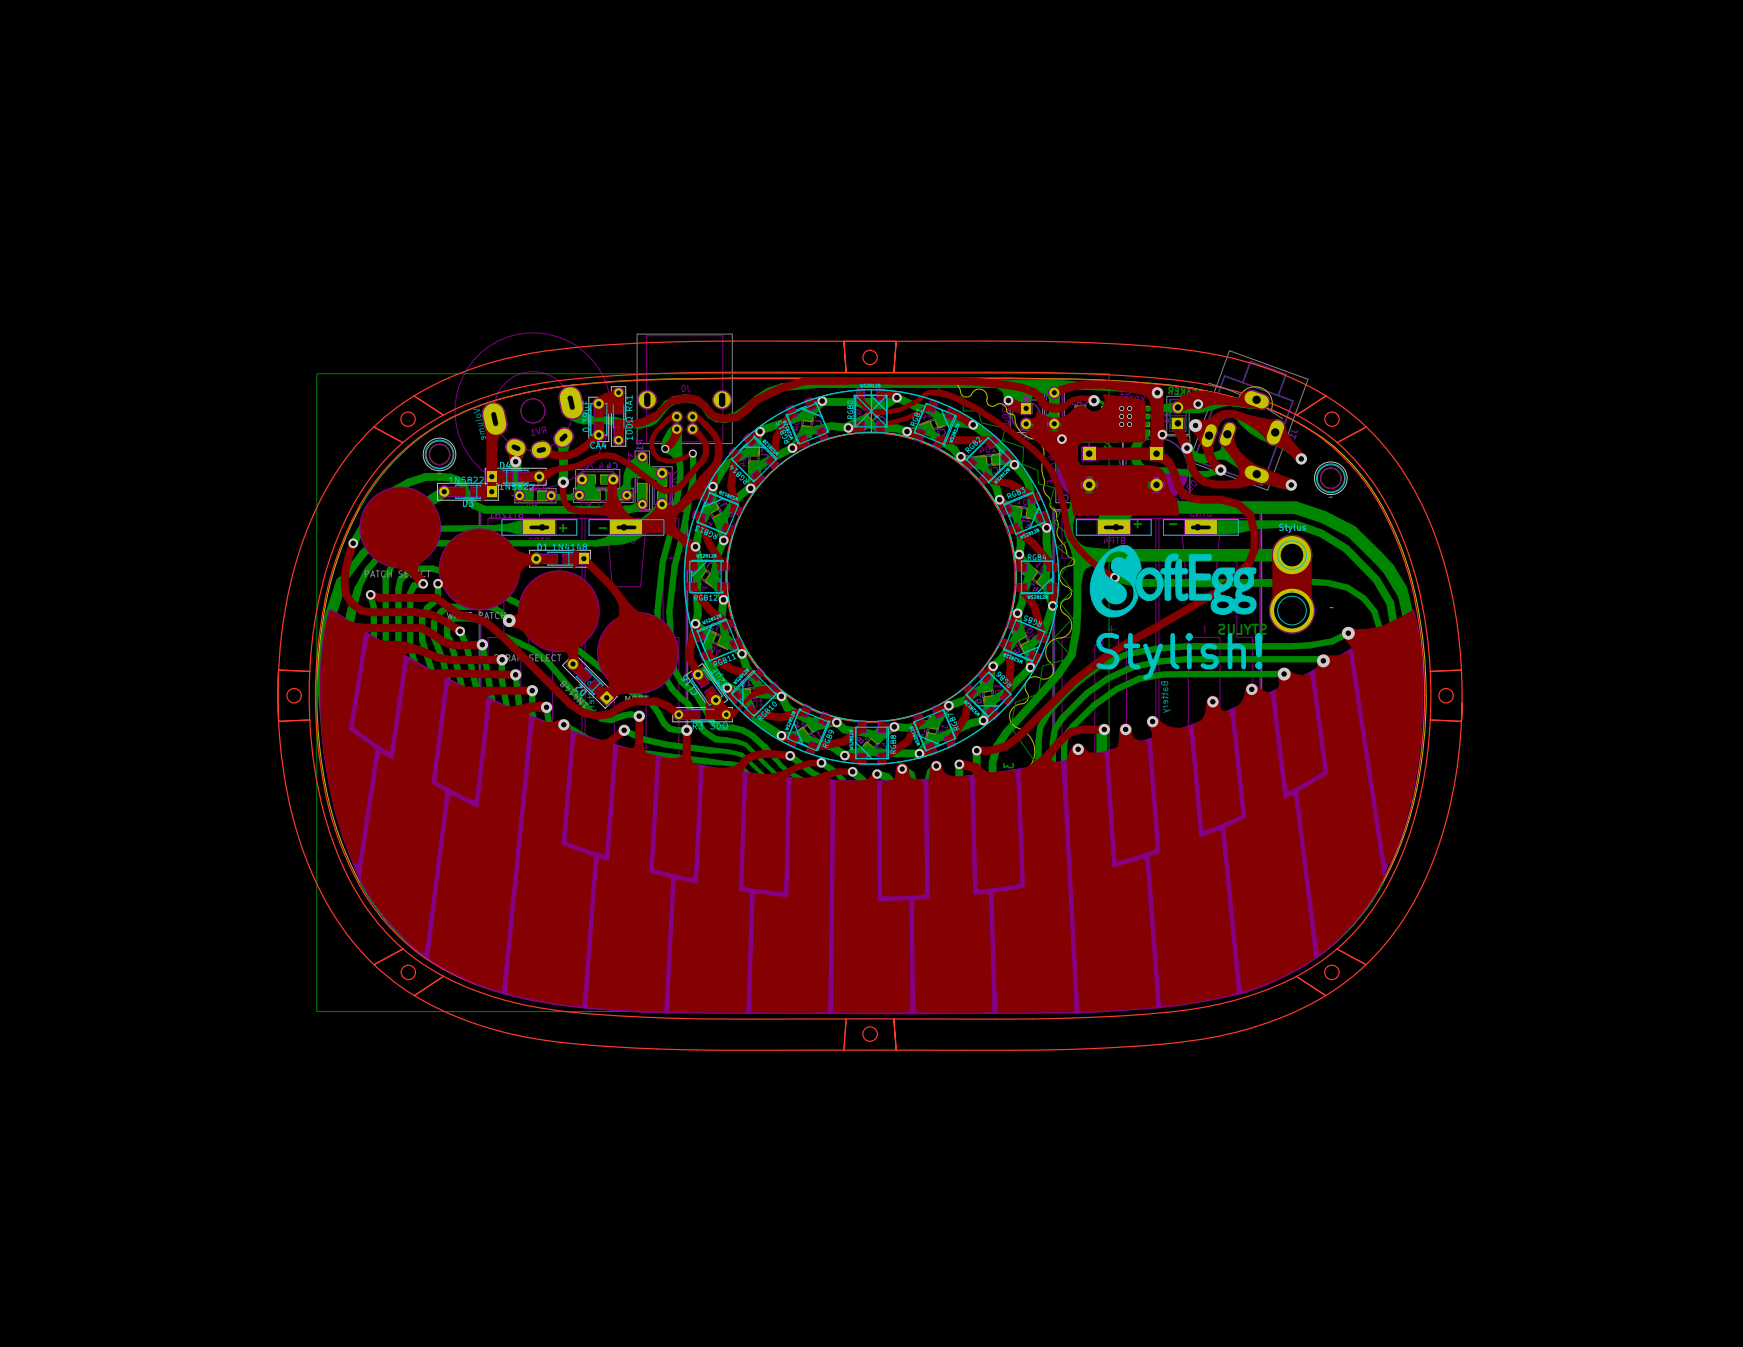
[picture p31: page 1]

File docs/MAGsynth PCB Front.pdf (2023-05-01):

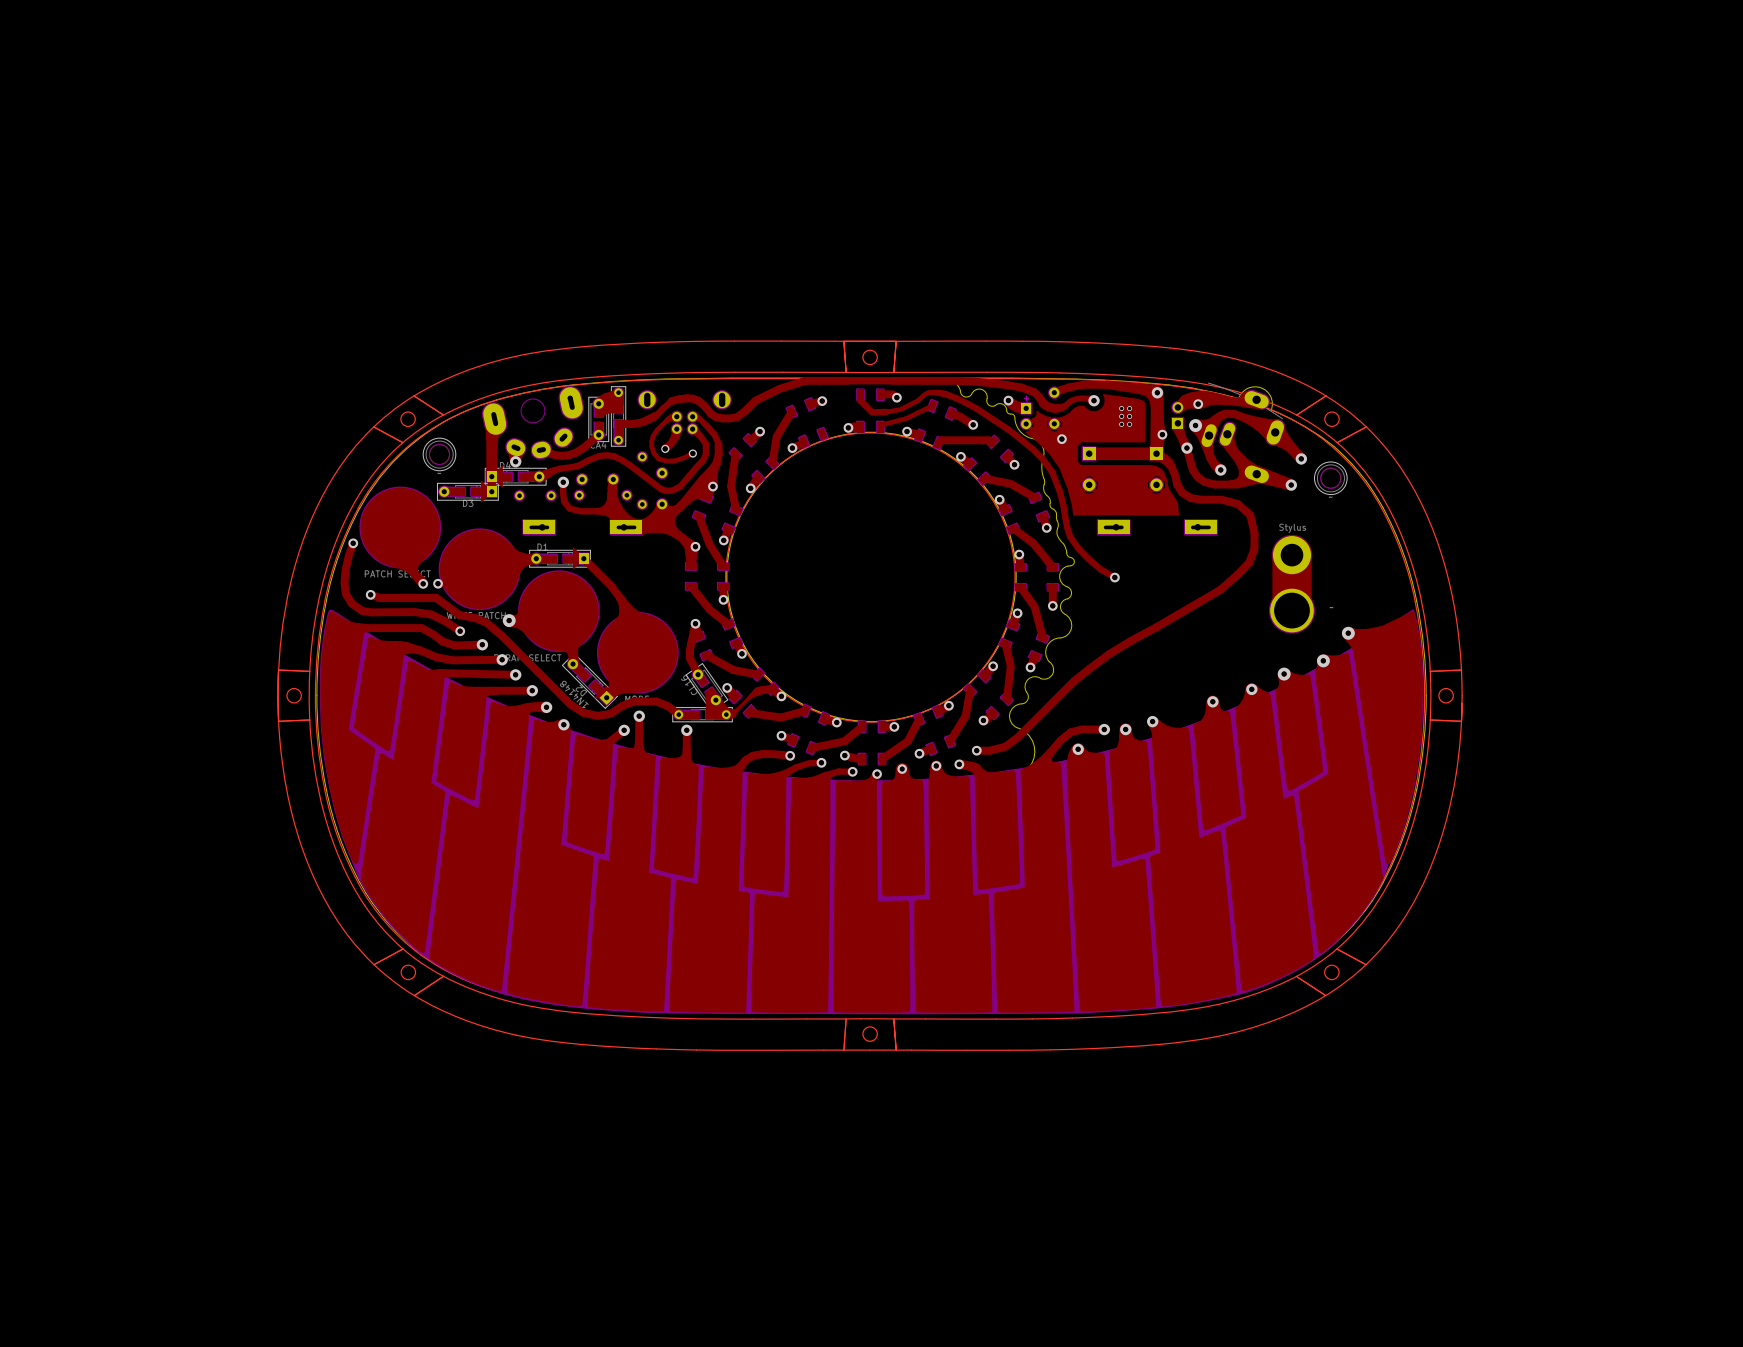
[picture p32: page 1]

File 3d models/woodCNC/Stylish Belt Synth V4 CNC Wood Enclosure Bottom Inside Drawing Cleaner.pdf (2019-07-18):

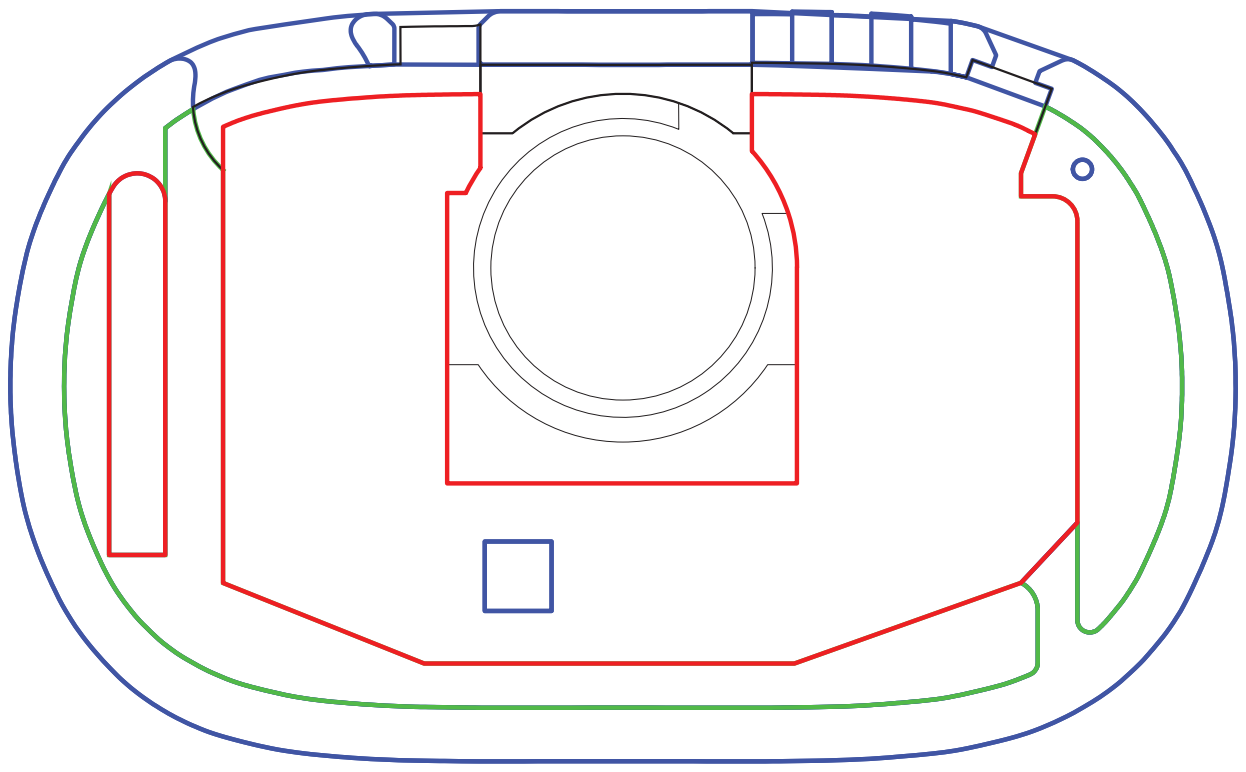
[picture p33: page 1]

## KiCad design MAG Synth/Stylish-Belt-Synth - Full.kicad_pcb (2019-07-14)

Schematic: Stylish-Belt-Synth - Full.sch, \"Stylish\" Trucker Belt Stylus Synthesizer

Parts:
BT12, BT34: AA_Battery_Dual_Terminal
BT12H1, BT34H1: Battery; BatteryHolder_Keystone_2462_2xAA
BTN1, BTN3: -; AA_Battery_-_Terminal
BTP2, BTP4: +; AA_Battery_+_Terminal
C1: 220nF; C_Disc_D5.0mm_W2.5mm_P5.00mm+SMD
C2: 1000μF; CP_Radial_D10.0mm_P5.00mm
C3: 470μF; CP_Radial_D10.0mm_P5.00mm
C4: 4.7nF; C_Disc_D5.0mm_W2.5mm_P5.00mm+SMD
CA1: 220µF; C_Disc_D5.0mm_W2.5mm_P5.00mm+SMD
CA2: 1μF; C_Disc_D5.0mm_W2.5mm_P5.00mm+SMD
CA3: 1μF; CP_Radial_Tantal_D4.5mm_P2.50mm
CA4: 0.39μF; C_Disc_D5.0mm_W2.5mm_P5.00mm+SMD
CL16: 22µF; C_Disc_D5.0mm_W2.5mm_P5.00mm+SMD
D1, D2: 1N4148; D_DO-35_SOD27_P7.62mm_Horizontal+SMD
D3, D4: 1N5822; D_DO-35_SOD27_P7.62mm_Horizontal+SMD
J0: USB_B
J1: Headphone; Stereo_Jack_3.5mm_Switch_Ledino_KB3SPRS
J26: WRITE PATCH; LargeRoundTouchPad
J27: PARAM SELECT; LargeRoundTouchPad
J28: PATCH SELECT; LargeRoundTouchPad
J29: MODE; LargeRoundTouchPad
J30: STYLUS; LargeRoundTouchPad
KB1: StylusKeyboardA; MAGWestSynthContactKeybed
LS1: Speaker; Pin_Header_Straight_1x02_Pitch2.54mm
R1: 330Ω; R_Axial_DIN0204_L3.6mm_D1.6mm_P7.62mm_Horizontal+SMD804
R2: 3.3kΩ; R_Axial_DIN0204_L3.6mm_D1.6mm_P7.62mm_Horizontal+SMD804
R3: 30Ω; R_Axial_DIN0204_L3.6mm_D1.6mm_P7.62mm_Horizontal+SMD804
R4: 33kΩ; R_Axial_DIN0204_L3.6mm_D1.6mm_P7.62mm_Horizontal+SMD804
RA1: 100Ω; R_Axial_DIN0204_L3.6mm_D1.6mm_P7.62mm_Horizontal+SMD804
RV1: Volume; Wheel_Pot_W_Switch_RV12_B103_FUSTAR
U1: stm32f103c8t6-module-china; stm32f103c8t6-module-china-smd
U2: XPT8871; SOIC-8-N

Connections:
/+3.3V: R3.2, U1.38 (3V3)
/+5V: C2.1, C3.1, CA1.1, CA2.1, RV1.4, U1.18 (5V), U2.6 (VDD)
/A0: KB1.9 (A0), U1.10 (A15/JTDI)
/A1: KB1.21 (A1), U1.27 (A2/U2TX)
/A#0: KB1.10 (A#0), U1.11 (B3/JTDO)
/A#1: KB1.22 (A#1), U1.28 (A3/U2RX)
/AUDIO_OUT: R1.2, U1.16 (B8/SCL1b/CANRX)
/B0: KB1.11 (B0), U1.12 (B4/JnTRST)
/B1: KB1.23 (B1), U1.29 (A4/NSS1)
/C0: KB1.0 (C0), U1.1 (B12/NSS2)
/C1: KB1.12 (C1), U1.13 (B5)
/C2: KB1.24 (C2), U1.30 (A5/SCK1)
/C#0: KB1.1 (C#0), U1.2 (B13/SCK2)
/C#1: KB1.13 (C#1), U1.14 (B6/SCL1a/U1TXb)
/D0: KB1.2 (D0), U1.3 (B14/MISO2)
/D1: KB1.14 (D1), U1.15 (B7/SDA1a/U1RXb)
/D#0: KB1.3 (D#0), U1.4 (B15/MOSI2)
/D#1: KB1.15 (D#1), U1.17 (B9/SDA1b/CANTX)
/E0: KB1.4 (E0), U1.5 (A8/MCO)
/E1: KB1.16 (E1), U1.22 (C13)
/F0: KB1.5 (F0), U1.6 (A9/U1TXa)
/F1: KB1.17 (F1), U1.23 (C14/OSC32_IN)
/F#0: KB1.6 (F#0), U1.7 (A10/U1RXa)
/F#1: KB1.18 (F#1), U1.24 (C15/OSC32_OUT)
/G0: KB1.7 (G0), U1.31 (A6/MISO1)
/G1: KB1.19 (G1), U1.25 (A0/WKUP)
/G#0: KB1.8 (G#0), U1.36 (B11/SDA2/U3RX)
/G#1: KB1.20 (G#1), U1.26 (A1)
/LED_DIN: U1.32 (A7/MOSI1); also elsewhere on the board
/PARAM: D2.2 (A), J27.1, U1.33 (B0)
/PATCH: J28.1, U1.35 (B10/SCL2/U3TX)
/PWM_OUT: CA4.2, RV1.2
/VIN: CL16.1, R3.1; also elsewhere on the board
/VUSB: D3.1 (K), D4.1 (K), RV1.5
/WRITE: D1.2 (A), J26.1, U1.34 (B1)
GND: BT12H1.2 (-), BTN1.1, C1.2, C2.2, C3.2, C4.2, CA1.2, CA2.2, CA3.2, CL16.2, J0.4 (GND), J30.1, RV1.1, U1.19 (GND), U1.39 (GND), U1.40 (GND), U2.1 (SD), U2.3 (MODE), U2.7 (GND); also elsewhere on the board
unnamed: BT12H1.1 (+), BT34H1.2 (-), BTN3.1, BTP2.1
unnamed: BT34H1.1 (+), BTP4.1, D3.2 (A)
unnamed: C1.1, R1.1, R2.2
unnamed: C4.1, R2.1, R4.2
unnamed: CA3.1, U2.2 (BYP)
unnamed: CA4.1, RA1.2
unnamed: D1.1 (K), D2.1 (K), J29.1
unnamed: D4.2 (A), J0.1 (VBUS)
unnamed: J0.2 (D-), U1.8 (A11/CANRX/USBDM)
unnamed: J0.3 (D+), U1.9 (A12/CANTX/USBDP)
unnamed: J1.1, J1.2, U2.8 (VOP)
unnamed: J1.3, LS1.2, U2.5 (VON)
unnamed: J1.4, J1.5, LS1.1
unnamed: RA1.1, U2.4 (IN)
unnamed: R4.1, RV1.3

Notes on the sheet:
R/C Circuit to convert PWM pulses to waveform
PCB UI Pads for Stylus
STM32F103C8T6 "Blue Pill" board
Amplifier Stage
PWM Output Filter
Power Input
Power filtering capacitors might be optional.
Switch is ganged with wheel potentiometer.
Headphone jack detaches speaker. Jumper 1,2,5,4 if no headphone jack.
Stylus is attached via banana plug.
Diode isolates USB power from battery power.
Diodes create 4th button input as 2nd and 3rd button simultaneous press.
Keyboard is pattern on front of PCB.
This capacitor eliminates LED ring noise!

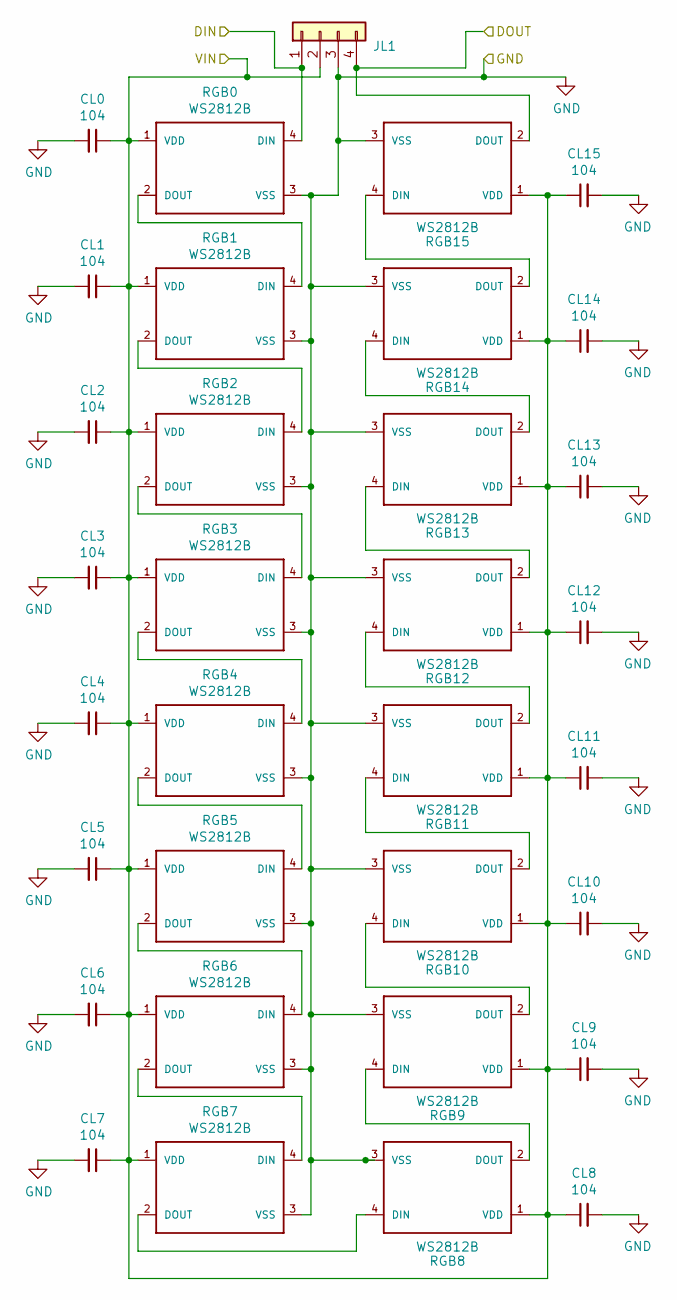
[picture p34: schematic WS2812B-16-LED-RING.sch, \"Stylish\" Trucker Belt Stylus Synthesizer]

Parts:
CL0, CL1, CL2, CL3, CL4, CL5, CL6, CL7, CL8, CL9, CL10, CL11, CL12, CL13, CL14, CL15: 104; C_0805_HandSoldering
JL1: Pin_Header_Straight_1x04_Pitch2.54mm
RGB0, RGB1, RGB2, RGB3, RGB4, RGB5, RGB6, RGB7, RGB8, RGB9, RGB10, RGB11, RGB12, RGB13, RGB14, RGB15: WS2812B

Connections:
/DOUT: JL1.4, RGB15.2 (DOUT)
/LED_DIN: JL1.1, RGB0.4 (DIN); also elsewhere on the board
/VIN: CL0.1, CL1.1, CL2.1, CL3.1, CL4.1, CL5.1, CL6.1, CL7.1, CL8.1, CL9.1, CL10.1, CL11.1, CL12.1, CL13.1, CL14.1, CL15.1, JL1.2, RGB0.1 (VDD), RGB1.1 (VDD), RGB2.1 (VDD), RGB3.1 (VDD), RGB4.1 (VDD), RGB5.1 (VDD), RGB6.1 (VDD), RGB7.1 (VDD), RGB8.1 (VDD), RGB9.1 (VDD), RGB10.1 (VDD), RGB11.1 (VDD), RGB12.1 (VDD), RGB13.1 (VDD), RGB14.1 (VDD), RGB15.1 (VDD); also elsewhere on the board
GND: CL0.2, CL1.2, CL2.2, CL3.2, CL4.2, CL5.2, CL6.2, CL7.2, CL8.2, CL9.2, CL10.2, CL11.2, CL12.2, CL13.2, CL14.2, CL15.2, JL1.3, RGB0.3 (VSS), RGB1.3 (VSS), RGB2.3 (VSS), RGB3.3 (VSS), RGB4.3 (VSS), RGB5.3 (VSS), RGB6.3 (VSS), RGB7.3 (VSS), RGB8.3 (VSS), RGB9.3 (VSS), RGB10.3 (VSS), RGB11.3 (VSS), RGB12.3 (VSS), RGB13.3 (VSS), RGB14.3 (VSS), RGB15.3 (VSS); also elsewhere on the board
unnamed: RGB0.2 (DOUT), RGB1.4 (DIN)
unnamed: RGB1.2 (DOUT), RGB2.4 (DIN)
unnamed: RGB2.2 (DOUT), RGB3.4 (DIN)
unnamed: RGB3.2 (DOUT), RGB4.4 (DIN)
unnamed: RGB4.2 (DOUT), RGB5.4 (DIN)
unnamed: RGB5.2 (DOUT), RGB6.4 (DIN)
unnamed: RGB6.2 (DOUT), RGB7.4 (DIN)
unnamed: RGB7.2 (DOUT), RGB8.4 (DIN)
unnamed: RGB8.2 (DOUT), RGB9.4 (DIN)
unnamed: RGB10.2 (DOUT), RGB11.4 (DIN)
unnamed: RGB9.2 (DOUT), RGB10.4 (DIN)
unnamed: RGB11.2 (DOUT), RGB12.4 (DIN)
unnamed: RGB12.2 (DOUT), RGB13.4 (DIN)
unnamed: RGB13.2 (DOUT), RGB14.4 (DIN)
unnamed: RGB14.2 (DOUT), RGB15.4 (DIN)

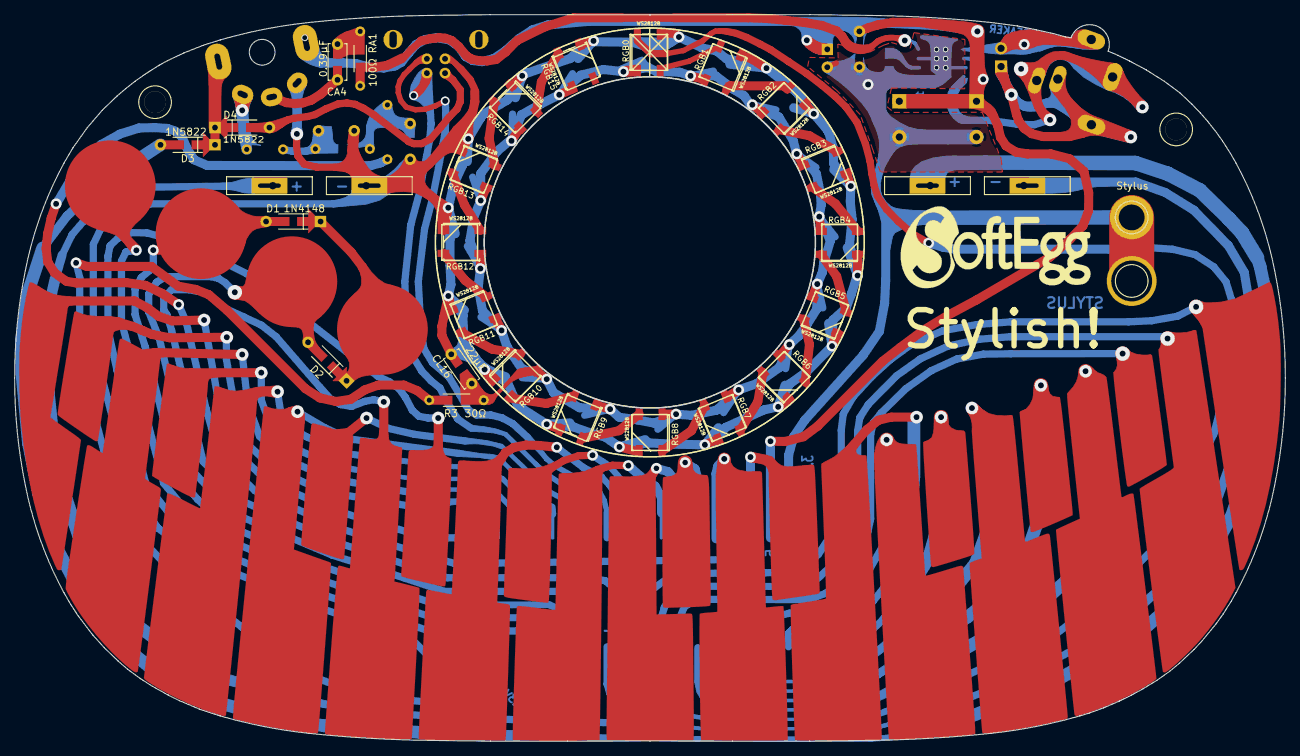
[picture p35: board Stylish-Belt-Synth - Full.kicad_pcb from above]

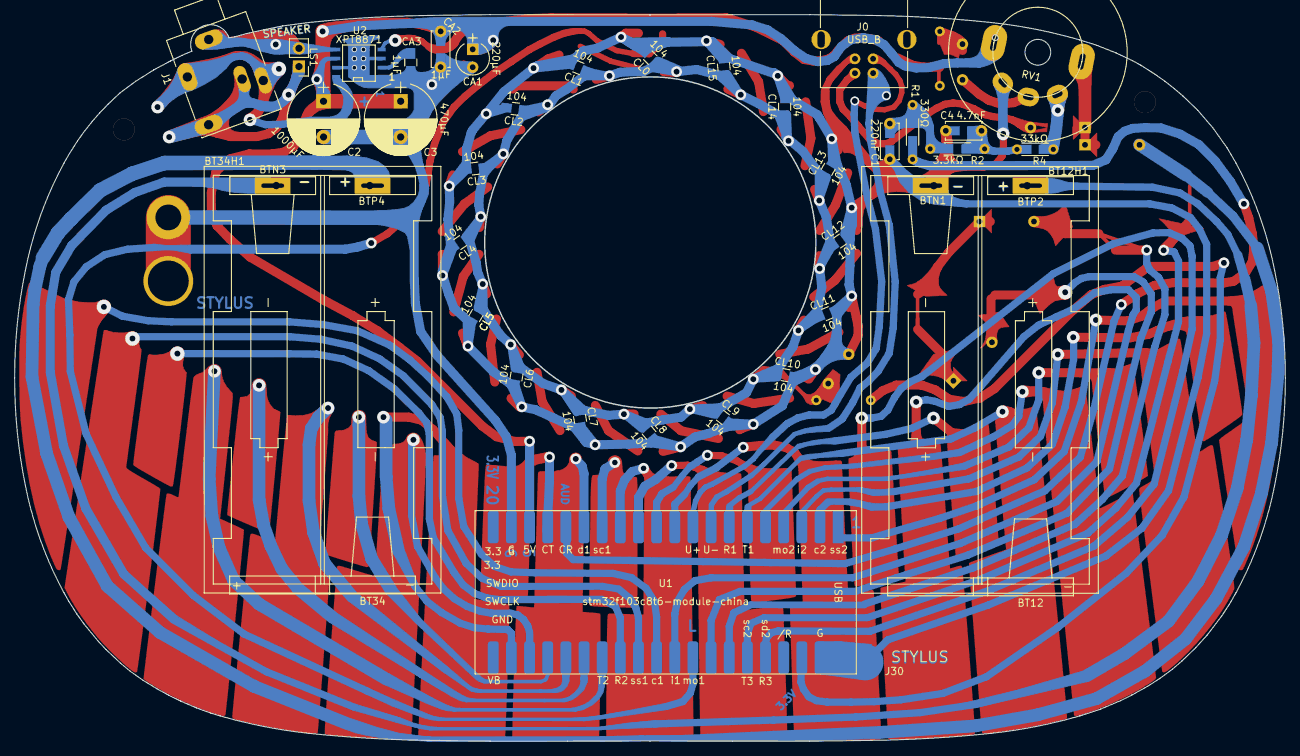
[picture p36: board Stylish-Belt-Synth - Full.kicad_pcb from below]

Board: 2 copper layers, 177.8 x 101.7 mm, 71 parts (41 on the bottom side), 66 nets.

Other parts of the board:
Stylus: Stylus; 1pin

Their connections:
GND: Stylus.1; also elsewhere on the board

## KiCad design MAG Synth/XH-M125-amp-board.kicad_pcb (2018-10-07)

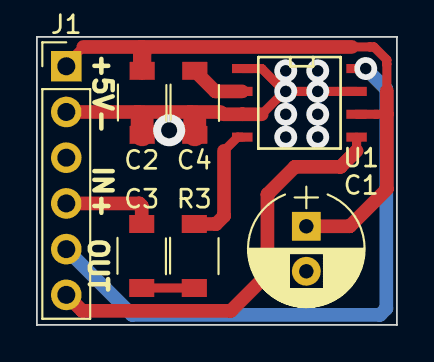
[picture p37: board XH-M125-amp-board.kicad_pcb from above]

Board: 2 copper layers, 20.0 x 16.0 mm, 7 parts (0 on the bottom side), 8 nets.

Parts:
C1: 470uF; CP_Radial_D6.3mm_P2.50mm
C2, C4: 1uF; C_1509
C3: 0.39uF; C_1509
J1: Conn_01x06; Pin_Header_Straight_1x06_Pitch2.54mm
R3: R; C_1509
U1: XPT8871; SOIC-8-N

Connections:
/GND: C1.2, C2.2, C4.2, J1.2, J1.3, U1.1, U1.3, U1.7
/VCC: C1.1, C2.1, J1.1, U1.6
/VIN: C3.2, J1.4
/VO1: J1.6, U1.5
/VO2: J1.5, U1.8
unnamed: C3.1, R3.2
unnamed: C4.1, U1.2
unnamed: R3.1, U1.4

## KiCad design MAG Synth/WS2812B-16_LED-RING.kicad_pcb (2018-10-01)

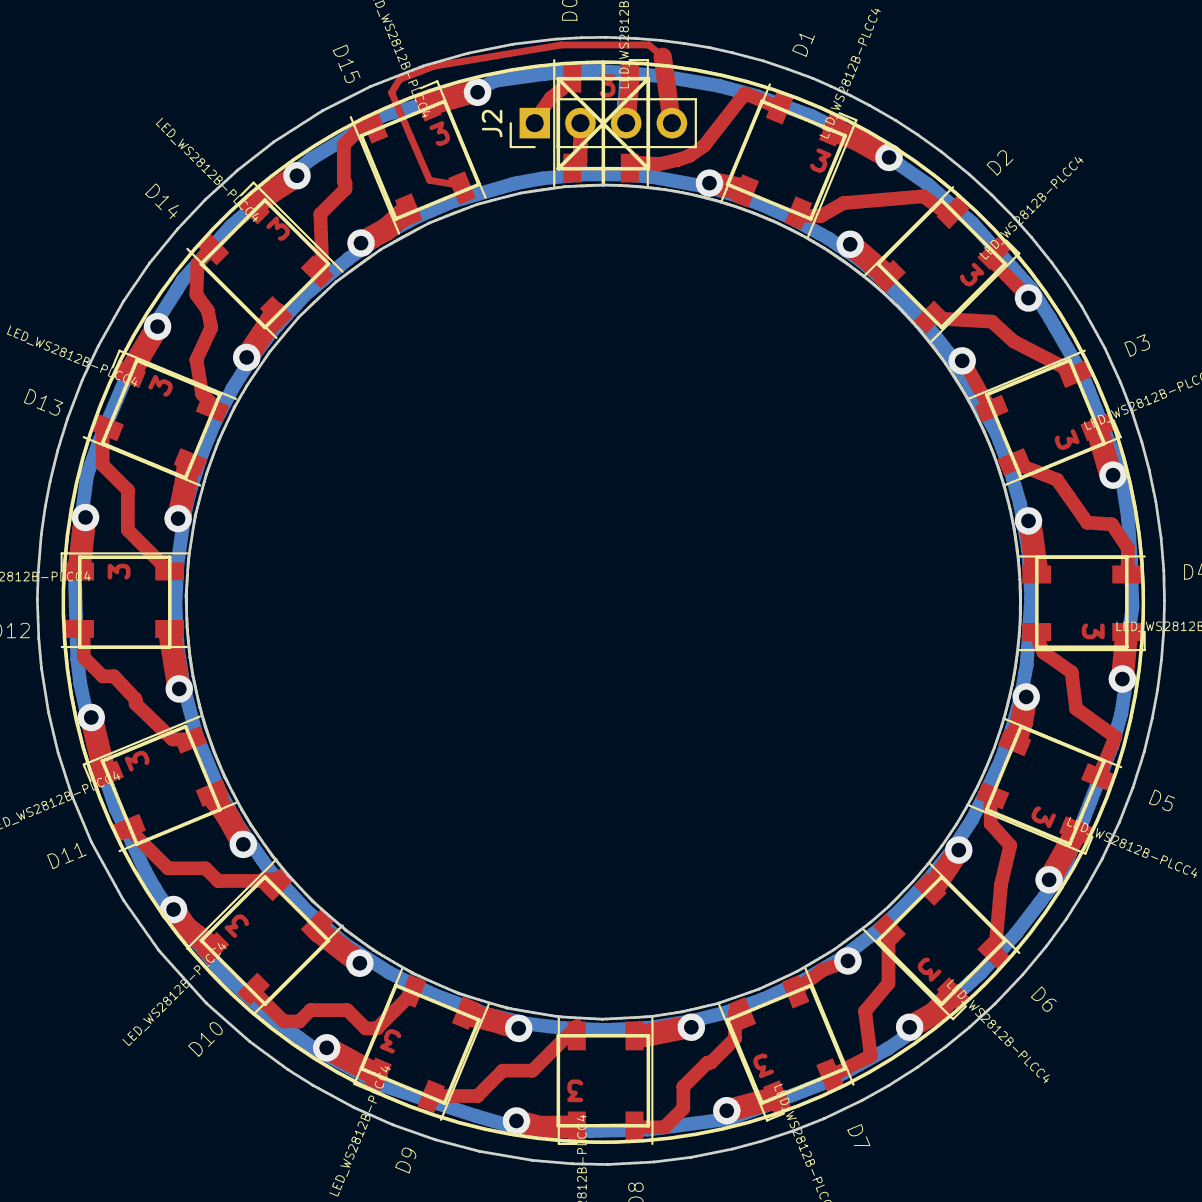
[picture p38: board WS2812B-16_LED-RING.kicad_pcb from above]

Board: 2 copper layers, 62.6 x 62.6 mm, 17 parts (0 on the bottom side), 19 nets.

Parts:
D0, D1, D2, D3, D4, D5, D6, D7, D8, D9, D10, D11, D12, D13, D14, D15: LED_WS2812B-PLCC4
J2: Pin_Header_Straight_1x04_Pitch2.54mm

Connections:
/WS2812B-16-LED-RING/5V: D0.1, D1.1, D2.1, D3.1, D4.1, D5.1, D6.1, D7.1, D8.1, D9.1, D10.1, D11.1, D12.1, D13.1, D14.1, D15.1, J2.2
/WS2812B-16-LED-RING/DIN: D0.4, J2.1
/WS2812B-16-LED-RING/DOUT: D15.2, J2.4
/WS2812B-16-LED-RING/GND: D0.3, D1.3, D2.3, D3.3, D4.3, D5.3, D6.3, D7.3, D8.3, D9.3, D10.3, D11.3, D12.3, D13.3, D14.3, D15.3, J2.3
unnamed: D0.2, D1.4
unnamed: D1.2, D2.4
unnamed: D2.2, D3.4
unnamed: D3.2, D4.4
unnamed: D4.2, D5.4
unnamed: D5.2, D6.4
unnamed: D6.2, D7.4
unnamed: D7.2, D8.4
unnamed: D8.2, D9.4
unnamed: D10.2, D11.4
unnamed: D9.2, D10.4
unnamed: D11.2, D12.4
unnamed: D12.2, D13.4
unnamed: D13.2, D14.4
unnamed: D14.2, D15.4

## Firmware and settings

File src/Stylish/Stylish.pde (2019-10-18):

//ws2812b setup
#include <WS2812B.h>
#define NUM_LEDS 16

WS2812B strip = WS2812B(NUM_LEDS);

#include "rgb.h"
#include "flashwriter_user.h"


#include <MozziGuts.h>
#include <Oscil.h> // oscillator template
#include <tables/saw2048_int8.h> // saw table for oscillator
#include <tables/square_no_alias_2048_int8.h> // square table for oscillator
#include <tables/triangle2048_int8.h> // sine table for oscillator
#include <tables/sin2048_int8.h> // sine table for oscillator
#include <LowPassFilter.h>

#include <mozzi_midi.h>
#include <mozzi_rand.h>
#include <ADSR.h>

#define FLASH_TOP (0x080020000)

#define DEBUG_PRINTF Serial.printf
#define DEBUG_APRINTLN Serial.println
#define DEBUG_APRINT Serial.print
//#define DEBUG_PRINTF( __xxx__, ...)
//#define DEBUG_APRINTLN( __xxx__, ...)
//#define DEBUG_APRINT( __xxx__, ...)


//#include "printf.h"
// use: Oscil <table_size, update_rate> oscilName (wavetable), look in .h file of table #included above
Oscil <SIN2048_NUM_CELLS, CONTROL_RATE> lfo(SIN2048_DATA);
Oscil <SQUARE_NO_ALIAS_2048_NUM_CELLS, AUDIO_RATE> osc1(SQUARE_NO_ALIAS_2048_DATA);
//Oscil <SAW2048_NUM_CELLS, AUDIO_RATE> osc1(SAW2048_DATA);
Oscil <SAW2048_NUM_CELLS, AUDIO_RATE> osc2(SAW2048_DATA);

// use #define for CONTROL_RATE, not a constant
//#define CONTROL_RATE 64 // Hz

#define CONTROL_RATE 256 // faster than usual to help smooth CONTROL_RATE adsr interpolation (next())

ADSR <CONTROL_RATE, CONTROL_RATE> envelope;

LowPassFilter lpf;

#define NUM_PATCHES (25)

uint8_t gain=0;
uint8_t note1_ofs=36;
uint8_t note2_ofs=43;
float   fine_freq1=-0.1;
float   fine_freq2=0.1;
uint8_t noise_max;
uint8_t filter_q=0;
uint8_t filter_f=0;
uint8_t lfo_rising_speed=0;
uint8_t pulse_width=0;
uint8_t env_to_pitch1=0.0f;
uint8_t env_to_pitch2=0.0f;
uint8_t env_to_pwm=0;
uint8_t env_to_noise=0;
uint8_t lfo_to_filter=0;
float lfo_to_pitch=0.0f;
uint8_t lfo_to_volume=0;
uint8_t lfo_to_pwm=0;
uint8_t lfo_to_noise=0;
uint8_t balance=0;
float   lfo_pitch_add=0.0f;
float   env_sustain_pitch_sub=0.0f;

float osc1_freq=0.0f;
float osc2_freq=0.0f;
uint8_t noise_gain=255;


uint8_t patch_number=0;
uint8_t last_patch_number=0;
uint8_t parameter_number=0;
bool patch_number_changed = false;
uint8_t current_mode_button = 0;
uint8_t mode_parameter_number=0;
uint8_t mode_value=0;
uint8_t parameter_value=0;

uint8_t last_ui_value=0;
bool note_off_processed = false;


// patch structure
// 26 parameters packed into 
#define NUM_PATCH_PARAMETERS (26)
#define LAST_PATCH_PARAMETER_NUMBER (NUM_PATCH_PARAMETERS-1)

enum e_PATCH_WAVEFORMS
{
  PPW_SAW,
  PPW_SQUARE,
  PPW_TRI,
  PPW_SINE,
};

enum ePATCH_PARAMS
{
  PP_WAVE1,       // waveform + octave
   PP_NOTE1,       // note
  PP_WAVE2,       // waveform + octave
   PP_NOTE2,       // note
  PP_NOISE,       // amount of noise  
  
  PP_DETUNE,      // fine pitch difference between oscillators   
   PP_ATTACK,      // ADSR envelope
  PP_DECAY,       // ADSR envelope
   PP_SUSTAIN,     // ADSR envelope
  PP_RELEASE,     // ADSR envelope  
   PP_FILTER_Q,    // Filter resonance  
  PP_FILTER_F,    // filter frequency  
  
  
  PP_LFO_WAVE,    // Waveform for LFO
   PP_LFO_FREQ,    // Frequency for LFO
  PP_LFO_RAMP,    // start speed of LFO
   PP_PULSE_WIDTH, // pulse width for square waves  
  PP_ENV_FILTER,  // amount of envelope applied to filter  
  
  PP_ENV_PITCH,   // amount of envelope applied to pitch of oscillators
   PP_ENV_PULSE_WIDTH, //amount of envelope to pulse width
  PP_ENV_NOISE,   // amount of envelope to noise
   PP_LFO_FILTER,  // amount of LFO applied to filter
  PP_LFO_PITCH,   // amount of LFO applied to pitch
   PP_LFO_VOLUME,  // amount of LFO applied to volume
  PP_LFO_PULSE_WIDTH, //amount of LFO to pulse width
  
  
  PP_LFO_NOISE,   // amount of LFO to noise
  PP_BALANCE,     // relative volume of wave 1 to wave 2
  PP_NUM_PARAMETERS  
};

enum eMODE_PARAMS
{
  MP_LED_BRIGHT,
  MP_COARSE_PITCH,
  MP_FINE_PITCH,
  MP_NUM_PARAMETERS
};

__attribute__ ((aligned (4))) uint8_t LocalPatchData[ NUM_PATCH_PARAMETERS ];
__attribute__ ((aligned (4))) uint8_t LocalPatchDataBackup[ NUM_PATCH_PARAMETERS ];

__attribute__ ((aligned (4))) uint8_t internal_patch_data[25][16]={
{0x18,0x06,0x70,0x10,0x10,0xc5,0x40,0x99,0x00,0x03,0x00,0x00,0x64,0x00,0x00,0x00},
{0xa8,0x2a,0xc4,0x90,0x10,0xc0,0x00,0x99,0x00,0x03,0x00,0x00,0x60,0x00,0x00,0x00},
{0x48,0x12,0x7f,0x00,0x23,0x59,0xc0,0x99,0x00,0x03,0x00,0x00,0x60,0x00,0x00,0x00},
{0x48,0x12,0xcf,0x11,0x50,0xc5,0x40,0x99,0x00,0x03,0x00,0x00,0x60,0x00,0x00,0x00},
{0x48,0x12,0x7f,0x10,0x10,0xc5,0x41,0x59,0x00,0x03,0x00,0x00,0x60,0x00,0x00,0x00},
{0x50,0x14,0x00,0x0c,0x15,0xc1,0x53,0x6c,0x00,0x00,0xc0,0x00,0x60,0x00,0x00,0x00},
{0x70,0x2a,0x74,0x90,0x10,0xc5,0x81,0x89,0x00,0x03,0xc0,0x00,0x64,0x00,0x00,0x00},
{0x2e,0x0a,0x5f,0x11,0x10,0xc1,0x40,0x09,0x00,0x03,0x00,0x00,0x64,0x30,0x00,0x00},
{0x48,0x12,0x77,0x12,0x70,0xc5,0x47,0x79,0x00,0x03,0x00,0x00,0x60,0x00,0x00,0x00},
{0x50,0x14,0x00,0x0c,0x15,0x4c,0xd3,0x8c,0x1c,0x00,0xc0,0x00,0x69,0xc4,0x00,0x00},
{0x10,0x1d,0x0f,0x02,0xb7,0x85,0xc0,0x9a,0x84,0x03,0x00,0x00,0x64,0x00,0x00,0x00},
{0x30,0x0c,0x0f,0x10,0x02,0x00,0xb1,0x49,0x00,0x03,0x00,0x00,0x64,0x00,0x00,0x00},
{0x30,0x0c,0x0c,0x10,0x0b,0x02,0xf0,0x09,0x00,0x03,0x00,0x00,0x64,0x00,0x00,0x00},
{0x18,0x06,0x07,0x0a,0x70,0xc4,0x41,0x73,0x9c,0x03,0xc0,0x00,0x64,0x60,0x00,0x00},
{0x18,0x06,0x70,0x10,0x17,0x2d,0x41,0x8a,0xb4,0x03,0xc0,0x00,0x64,0x1c,0x00,0x00},
{0x18,0x06,0x00,0x10,0x10,0xc5,0x4f,0x80,0x28,0x03,0x00,0x00,0x64,0x03,0x18,0x00},
{0x18,0x06,0x70,0x10,0x10,0xc5,0x40,0x99,0x00,0x03,0x03,0x00,0x64,0x00,0x00,0x00},
{0x30,0x0c,0x0c,0x10,0x17,0x02,0xf0,0x09,0x00,0x03,0x00,0x00,0x64,0x00,0x00,0x00},
{0x20,0x12,0x0f,0x04,0x10,0xc5,0x40,0x97,0x24,0x03,0xc0,0x00,0x60,0x24,0x00,0x00},
{0x48,0x14,0x4f,0x04,0x10,0xc0,0x00,0x93,0x9c,0x03,0xc0,0x01,0x20,0x5c,0x00,0x00},
{0x78,0x22,0xcf,0x10,0x09,0x02,0x40,0x99,0x00,0x03,0x00,0x00,0x64,0x00,0x00,0x00},
{0x20,0x08,0xc0,0x10,0x11,0x04,0xc1,0x18,0x94,0x03,0xc0,0x00,0x64,0xcc,0x00,0x00},
{0x00,0x00,0x7c,0x10,0x10,0xc5,0x40,0x9a,0x80,0x03,0x06,0x00,0x64,0x80,0x00,0x00},
{0x28,0x1c,0x00,0x11,0x70,0xc3,0x01,0x88,0x9c,0x03,0xc0,0x00,0x63,0x80,0x00,0x00},
{0x48,0x16,0x00,0x04,0x53,0x80,0x00,0x59,0x28,0x03,0x00,0x00,0x60,0x14,0x00,0x00},
};

class patch_t
{
private:
	uint8_t values[16];
public:
	bool Set(uint8_t param, uint8_t value)
	{
		uint8_t bitindex = param * 5;
		uint8_t bitsize = 5;
		if (param == LAST_PATCH_PARAMETER_NUMBER)
		{
			bitsize = 3;
		}
		uint8_t byteindex = bitindex >> 3; // divide by 8 to get the byte in "values" array

		int shift = 16 - ((bitindex & 0x7) + bitsize); // keep low 4 bits for "modulus 8" behavior to get bit index 

		uint16_t work = value << shift;  // shift value into position using 16 bit int.
		uint16_t mask = (1 << bitsize) - 1;  // create a mask for the proper number of bits
		mask <<= shift;                   //shift the mask into position
//		printf("param: %d value:%d bitsize:%d bitindex: %d byteindex:%d shift:%d mask:%016lld work:%016lld ~mask:%016lld ", param, value, bitsize, bitindex, byteindex, shift, ToBinary(mask),ToBinary(work),ToBinary(~mask));

		uint16_t old = (values[byteindex] << 8) | values[byteindex + 1]; //get the data currently in position
//		printf("old:%016lld ", ToBinary(old));
		old &= ~mask; //mask off the area where the data needs to go.
//		printf("old(masked):%016lld ", ToBinary(old));

		work |= old;  //install the old data around the shifted value in the work data
//		printf("work(combined):%016lld ", ToBinary(work));

		values[byteindex] = work >> 8;        //
		values[byteindex + 1] = work & 0xFF;

//		printf(" values[%d,%d]=%02x,%02x\n", byteindex, byteindex + 1, values[byteindex], values[byteindex + 1]);

		return(false);                      //no errors, return
	};
	uint8_t Get(uint8_t param)
	{
		uint8_t bitindex = param * 5;
		uint8_t bitsize = 5;
		if (param == LAST_PATCH_PARAMETER_NUMBER)
		{
			bitsize = 3;
		}
		uint8_t byteindex = bitindex >> 3; // divide by 8 to get the byte in "values" array
		int shift = 16 - ((bitindex & 0x7) + bitsize); // keep low 4 bits for "modulus 8" behavior to get bit index 

		uint16_t work = (values[byteindex] << 8) | values[byteindex + 1]; //get the data currently in position
		work >>= shift;
		uint16_t mask = (1 << bitsize) - 1;  // create a mask for the proper number of bits
		work &= mask;
//		printf("Get: %d\n", work);
		return (work);
	};
  
  void Echo()
  {
    uint32_t patch_num_calculate = ( (uint32_t) this - (uint32_t) internal_patch_data ) / 16;
    
    DEBUG_PRINTF("Patch[%d].values=\r\n{",patch_num_calculate);
    for( uint8_t i=0; i < 16; i++ )
    {
      DEBUG_PRINTF("0x%02X,",values[i]);
    }
    DEBUG_PRINTF("\r\n");
  }
  
  void GetAllToLocal()
  {
    DEBUG_PRINTF("GetAllToLocal\r\n");
    for( uint8_t i=0; i < NUM_PATCH_PARAMETERS; i++ )
    {
      LocalPatchData[i] = Get( i );
    }
    Echo();
  }
  
  void SetAllFromLocal()
  {
    DEBUG_PRINTF("SetAllFromLocal\r\n");
    for( uint8_t i=0; i < NUM_PATCH_PARAMETERS; i++ )
    {
      Set( i, LocalPatchData[i] );
    }
   
    Echo();
  }  
};



patch_t * Patch = (patch_t *) internal_patch_data;
//[NUM_PATCHES];

uint32_t * FlashAddress = NULL;

#define NUMBER_MODE_VALUES (25)

__attribute__ ((aligned (4))) uint8_t ModeData[NUMBER_MODE_VALUES];

//order of operations:
// tap button for thing to change - ring will be a solid color, different for each button
// when released, ring will flash that color, waiting for input value
// keyboard is used to select value, and will light up LED corresponding to value while held.
// when released, ring will flash faster than before, keyboard can still be used to change value
// when original button is pressed again, value is kept, ring flashes once and fades out
// if another button is pushed, change is aborted and ring flashes red, value reverts.
// for parameters, it is a two stage process, parameter number, then parameter value.
// after parameter number is selected, further presses will change parameter value

enum eUI_States {
  S_PLAY,               //just play notes
  S_PATCH_SELECT,       //selecting patch. Takes 1 parameter (play sound) and verify with patch select button, (other button cancels)
  S_PATCH_WRITE,        //writing patch.   Takes 1 parameter (play sound) and verify with patch write button, (other button cancels)
  S_PARAMETER_SELECT,   //changing parameter. Step 1, select parameter #, automatically advances to next state: change parameter value (other button cancels)
  S_PARAMETER_VALUE,    //changing parameter. Step 2. select the value, play the sound with updated value, verify change with parameter button (other button cancels)
  S_MODE_CHANGE,        //changing mode. Step 1. Select the mode parameter number, automatically advances to next state: change mode value (other button cancels)
  S_MODE_VALUE,         //changing mode. Step 2, select the value for mode parameter. verify change with mode button (other button cancels)
  S_NUM_STATES
};

char * UI_State_Strings[]={
  "S_PLAY",
  "S_PATCH_SELECT",       
  "S_PATCH_WRITE",        
  "S_PARAMETER_SELECT",   
  "S_PARAMETER_VALUE",    
  "S_MODE_CHANGE",        
  "S_MODE_VALUE",         
  "S_NUM_STATES"  
};

enum eUI_SubStates {
  SS_UP,
  SS_PLAY_DOWN,
  SS_SELECT_DOWN,
  SS_SELECT_WAIT_FOR_VALUE,
  SS_SELECT_PLAYING_VALUE_AUDITION,
  SS_SELECT_DONE_SELECTING_DOWN,
  SS_SELECT_ABORT_DOWN,
  SS_NUM_STATES
};

char * UI_SubState_Strings[] = {
  "SS_UP",
  "SS_PLAY_DOWN",
  "SS_SELECT_DOWN",
  "SS_SELECT_WAIT_FOR_VALUE",
  "SS_SELECT_PLAYING_VALUE_AUDITION",
  "SS_SELECT_DONE_SELECTING_DOWN",
  "SS_SELECT_ABORT_DOWN",
  "SS_NUM_STATES"
};


enum eANIM_Bits {
  eANIM_NONE     = 0,
  eANIM_FLASH    = 1,
  eANIM_DIAL     = 2,
  eANIM_FADE     = 4,
  eANIM_SPARKLES = 8
};

eUI_States state = S_PLAY;
eUI_SubStates subState = SS_UP;

//stylus keyboard 
uint8_t keyboard_pins[]={PB12,PB13,PB14,PB15,PA8,PA9,PA10,PA6,PB11,PA15,PB3,PB4,PB5,PB6,PB7,PB9,PC13,PC14,PC15,PA0,PA1,PA2,PA3,PA4,PA5,
/*buttons */             PB10,PB1,PB0,/*,PA6*/};

#define NUM_NOTES (25)
#define NUM_BUTTONS (3) /*mode button being used for keyboard atm...*/
#define NUM_PINS (NUM_NOTES+NUM_BUTTONS)
#define NOT_PRESSED (0xFF)
#define REQUIRED_STABLE_CYCLES (100)

enum {PATCH_BUTTON=NUM_NOTES, WRITE_BUTTON, VALUE_BUTTON, MODE_BUTTON};

#define MODE_BUTTON_HACK_MASK ((1<<WRITE_BUTTON)|(1<<VALUE_BUTTON))
#define MODE_BUTTON_MASK (1<<MODE_BUTTON)

typedef void ( *KeyCallback)(uint8_t key);

uint32_t raw_key_bits=0;
uint32_t key_bits=0;
uint8_t key_down = NOT_PRESSED;
uint8_t last_key_down = NOT_PRESSED;
uint8_t raw_key_down = NOT_PRESSED;
uint8_t last_key_played = NOT_PRESSED;
KeyCallback KeyDownCallback=NULL;
KeyCallback KeyUpCallback=NULL;
uint32_t stable_counter=0;
uint16_t env_to_filter=0;
char MAGIC[] = "STYLISH1";

void SetFlashAddress()
{
  setupFLASH();    
  FlashAddress = (uint32_t *) (getFlashEnd() - getFlashPageSize());
  DEBUG_PRINTF("FlashAddress: 0x%08X\r\n",(uint32_t)FlashAddress);
};

void WritePatchesToFlash()
{
  uint32_t * writeAddress = FlashAddress;
  //write to flash
  flashUnlock();
  flashErasePage( (uint32_t) writeAddress );
  
  uint32_t * source = (uint32_t *)internal_patch_data;
  DEBUG_PRINTF("WritePatchesToFlash: 0x%l08X <- 0x%l08x\r\n",(uint32_t)FlashAddress,(uint32_t)source);
  DEBUG_APRINTLN((uint32_t)FlashAddress,HEX);
  DEBUG_APRINTLN((uint32_t)source,HEX);
  
  for( uint16_t i=0; i < sizeof(patch_t)*NUM_PATCHES/4; i++ )
  {
    flashWriteWord((u32)(writeAddress++), *(u32 *)(source +i));      
  } 
  //write magic number
  source = (u32*) MAGIC;
  flashWriteWord((u32)(writeAddress++), *(u32 *)(source++));      
  flashWriteWord((u32)(writeAddress++), *(u32 *)(source++));      
  flashLock();    
};

void ReadPatchesFromFlash()
{
  uint32_t * magic = (uint32_t *) MAGIC;
  uint32_t byte_count = (sizeof(patch_t)*NUM_PATCHES);
  DEBUG_PRINTF("ReadPatchesFromFlash: 0x%l08X -> 0x%l08x  (%d)\r\n",FlashAddress,internal_patch_data, byte_count);
  //IF first button held 
  if (!digitalRead(PB10))
  {
    DEBUG_PRINTF("ALL PATCH RESET DETECTED\r\n");
  }
  else if (( FlashAddress[byte_count/4]==magic[0]) && ( FlashAddress[(byte_count/4)+1]==magic[1]))
  {
    DEBUG_PRINTF("MAGIC detected!\r\n");
  }
  else return;  
  
  DEBUG_APRINTLN((uint32_t)FlashAddress,HEX);
  DEBUG_APRINTLN((uint32_t)internal_patch_data,HEX);
  memcpy(internal_patch_data,FlashAddress, byte_count );
  
  uint8_t * patch_data = (uint8_t*) internal_patch_data;
  for(int i=0; i< byte_count; i++){
    DEBUG_PRINTF("0x%02x,",*patch_data++);
    if ( ((i+1)%16) == 0 )
    {
      DEBUG_PRINTF("\r\n");
    }
  }
/*  
  for( int i=0; i< NUM_PATCHES; i++)
  {
    patch_number = i;
    Patch[i].GetAllToLocal();
    uint8_t oct = LocalPatchData[PP_WAVE1]/3;
    uint8_t wave = LocalPatchData[PP_WAVE1]%3;
    if (oct>5) oct=5;
    LocalPatchData[PP_WAVE1]=oct+wave*6;
    oct = LocalPatchData[PP_WAVE2]/3;
    wave = LocalPatchData[PP_WAVE2]%3;
    if (oct>5) oct=5;
    LocalPatchData[PP_WAVE1]=oct+wave*6;    
  }
  WritePatchesToFlash();
*/  
};


int8_t Noise()
{
  uint16_t noise_now = noise_gain * noise_max;
  noise_now >>=8;

  return( rand(noise_now) );
}

const unsigned int AttackTimes[25]={/*0,*/ 10,20,40,60, 80,100,110,120,130, 140,160,180,200,250, 300,400,500,600,700, 800,900,1000,2500,5000, 8000};
const unsigned int DecayTimes[25] ={/*0,*/ 10,20,40,60, 80,100,110,120,130, 140,160,180,200,250, 300,400,500,600,700, 800,900,1000,2500,5000, 8000};
const float LFOFreqencies[25]={0.1f,0.2f,0.3f,0.4f,0.5f, 0.6f,0.7f,0.8f,0.9,1.0f, 1.5f,1.6667f,2.0f,2.2167f,2.3333f, 2.6667f,3.0f,3.3333f, 3.6667f,4.0f, 6.0f,8.0f,10.0f,15.0f,20.0f};
const float LFOPitches[25]={0.00f,0.025f,0.05f,0.075f,0.1f,  0.15f,0.2f,0.25f,0.3f,0.35f, 0.4f,0.45f,0.5f,0.55f,0.6f, 0.7f,0.75f,0.8f,0.9f,1.0f,  2.0f,3.0f,5.0f,7.0f,12.0f};
const float EnvPitch1[25] ={0.0f, 0.035f,0.07f,0.1f,0.2f,0.4f, 0.8f,1.0f,3.0f,4.0f,5.0f, 7.0f,12.0f,0.035f,0.07f,0.1f, 0.2f,0.4f,0.8f,1.0f,3.0f, 4.0f,5.0f,7.0f,12.0f};
const float EnvPitch2[25]={0.0f, 0.035f,0.07f,0.1f,0.2f,0.4f, 0.8f,1.0f,3.0f,4.0f,5.0f, 7.0f,12.0f,0.000f,0.00f,0.0f, 0.0f,0.0f,0.0f,0.0f,0.0f, 0.0f,0.0f,0.0f,00.0f};

uint8_t MapValToByte( uint8_t value, uint8_t min=0, uint8_t max=255 );

uint8_t MapValToByte( uint8_t value, uint8_t min, uint8_t max )
{
  //return ( (value*10)+(value*3/5) );
  float work = (float)max - (float) min;
  work /=25.0f;
  work *= (float) value;
  work += (float) min;
  if ( work > 255.0f ) work = 255.0f;
  else if (work < 0.0f ) work = 0.0f;
  return( (uint8_t) work );  
}
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
void loop() 
{
  StylusKeyboardUpdate();
  uint8_t key = GetStylusKeyDown();

  if ((counter%SPEED_DIVIDE)==0)
  {
    uint64_t small_counter = counter/SPEED_DIVIDE;
    DEBUG_APRINT(small_counter,DEC);
    DEBUG_APRINT(" ");
    uint32_t bits=GetStylusKeyBits();
    uint32_t bit = 1;
    for(int i=0;i<NUM_PINS+1;i++)
    {
      if ( bits & bit )
      {
        DEBUG_APRINT("#");
      }
      else
      {
        DEBUG_APRINT(".");
      }
      bit<<=1;
    }
    DEBUG_APRINTLN("\e[1;A");
    AnimUpdate();
    
    //led strip test
/*
    for(int i=0; i< strip.numPixels(); i++) 
    {
      uint8_t r=0,g=0,b=0;
      if ((small_counter%strip.numPixels())==i)
      {
        r=127;
      }
      uint8_t keywrap = key % NUM_LEDS;
      if ( key < NUM_LEDS )
      {
        if ( i == key)
        {
          g=127;
        }
      }
      else
      {
        if ( i == keywrap)
        {
          b=127;
          g=32;
        }
      }
      strip.setPixelColor( i, r, g, b );
    }
    strip.show();
*/
    
    if ( key == NOT_PRESSED )
    {
      //if (!note_off_processed )
      {
        SoundKeyUp();
        note_off_processed = true;
      }
/*      if ( gain > 8 )
      {
        gain-=8;
      }
      else
      {
        gain = 0;
      }
*/    
    }
    else
    {
      note_off_processed = false;
    }
  }  
  
  counter++;
  audioHook();
}

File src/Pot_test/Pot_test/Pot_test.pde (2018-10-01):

//#include <Adafruit_NeoPixel-ANDnXOR.h>
#include <WS2812B.h>

#include <MozziGuts.h>
#include <Oscil.h> // oscillator template
#include <tables/sin2048_int8.h> // sine table for oscillator
#include <RollingAverage.h>
#include <ControlDelay.h>

#define INPUT_PIN 0 // analog control input

unsigned int echo_cells_1 = 32;
unsigned int echo_cells_2 = 60;
unsigned int echo_cells_3 = 127;

#define CONTROL_RATE 64
ControlDelay <128, int> kDelay; // 2seconds

// oscils to compare bumpy to averaged control input
Oscil <SIN2048_NUM_CELLS, AUDIO_RATE> aSin0(SIN2048_DATA);
Oscil <SIN2048_NUM_CELLS, AUDIO_RATE> aSin1(SIN2048_DATA);
Oscil <SIN2048_NUM_CELLS, AUDIO_RATE> aSin2(SIN2048_DATA);
Oscil <SIN2048_NUM_CELLS, AUDIO_RATE> aSin3(SIN2048_DATA);

// use: RollingAverage <number_type, how_many_to_average> myThing
RollingAverage <int, 32> kAverage; // how_many_to_average has to be power of 2
int averaged;

#if 0
#define PIN 6

// Parameter 1 = number of pixels in strip
// Parameter 2 = pin number (most are valid)
// Parameter 3 = pixel type flags, add together as needed:
//   NEO_KHZ800  800 KHz bitstream (most NeoPixel products w/WS2812 LEDs)
//   NEO_KHZ400  400 KHz (classic 'v1' (not v2) FLORA pixels, WS2811 drivers)
//   NEO_GRB     Pixels are wired for GRB bitstream (most NeoPixel products)
//   NEO_RGB     Pixels are wired for RGB bitstream (v1 FLORA pixels, not v2)
Adafruit_NeoPixel strip = Adafruit_NeoPixel(12, PIN, NEO_GRB + NEO_KHZ800);
int speed = 0;
#else
#define NUM_LEDS 16
/*
 * Note. Library uses SPI1
 * Connect the WS2812B data input to MOSI on your board.
 * 
 */
WS2812B strip = WS2812B(NUM_LEDS);
// Note. Gamma is not really supported in the library, its only included as some functions used in this example require Gamma
uint8_t LEDGamma[] = {
    0,  0,  0,  0,  0,  0,  0,  0,  0,  0,  0,  0,  0,  0,  0,  0,
    0,  0,  0,  0,  0,  0,  0,  0,  0,  0,  0,  0,  1,  1,  1,  1,
    1,  1,  1,  1,  1,  1,  1,  1,  1,  2,  2,  2,  2,  2,  2,  2,
    2,  3,  3,  3,  3,  3,  3,  3,  4,  4,  4,  4,  4,  5,  5,  5,
    5,  6,  6,  6,  6,  7,  7,  7,  7,  8,  8,  8,  9,  9,  9, 10,
   10, 10, 11, 11, 11, 12, 12, 13, 13, 13, 14, 14, 15, 15, 16, 16,
   17, 17, 18, 18, 19, 19, 20, 20, 21, 21, 22, 22, 23, 24, 24, 25,
   25, 26, 27, 27, 28, 29, 29, 30, 31, 32, 32, 33, 34, 35, 35, 36,
   37, 38, 39, 39, 40, 41, 42, 43, 44, 45, 46, 47, 48, 49, 50, 50,
   51, 52, 54, 55, 56, 57, 58, 59, 60, 61, 62, 63, 64, 66, 67, 68,
   69, 70, 72, 73, 74, 75, 77, 78, 79, 81, 82, 83, 85, 86, 87, 89,
   90, 92, 93, 95, 96, 98, 99,101,102,104,105,107,109,110,112,114,
  115,117,119,120,122,124,126,127,129,131,133,135,137,138,140,142,
  144,146,148,150,152,154,156,158,160,162,164,167,169,171,173,175,
  177,180,182,184,186,189,191,193,196,198,200,203,205,208,210,213,
215,218,220,223,225,228,231,233,236,239,241,244,247,249,252,255 };
#endif

void setup() {
  kDelay.set(echo_cells_1);
  startMozzi();

  //pinMode(PA0,INPUT_ANALOG);
  //pinMode(PA1,INPUT_ANALOG);
  //speed = analogRead(PA0);  
  strip.begin();
  strip.show(); // Initialize all pixels to 'off'
  strip.setBrightness(32);
  
}

int analog_in=0;

void my_delay(unsigned long time)
{
  unsigned long end_time = millis()+time;
  while( millis() < end_time )
  {
    //analog_in = analogRead(PA0);
    //strip.setBrightness(analog_in>>4);
    //speed = analogRead(PA1)>>4;
    audioHook();
  }
}

void updateControl(){
  int bumpy_input = mozziAnalogRead(INPUT_PIN);
  averaged = kAverage.next(bumpy_input);
  aSin0.setFreq(averaged);
  aSin1.setFreq(kDelay.next(averaged));
  aSin2.setFreq(kDelay.read(echo_cells_2));
  aSin3.setFreq(kDelay.read(echo_cells_3));
}


int updateAudio(){
  return 3*((int)aSin0.next()+aSin1.next()+(aSin2.next()>>1)
    +(aSin3.next()>>2)) >>3;
}

void loop() {
#if 0
  // Some example procedures showing how to display to the pixels:
  colorWipe(strip.Color(255, 0, 0), 10 + speed ); // Red
  speed++;
  colorWipe(strip.Color(0, 255, 0), 10 + speed ); // Green
  speed++;
  colorWipe(strip.Color(0, 0, 255), 10 + speed ); // Blue
  speed++;
  rainbow(5 + speed );
  speed++;
  rainbowCycle(5 + speed );
  speed++;
#else
  colorWipe(strip.Color(0, 255, 0), 20); // Green
  colorWipe(strip.Color(255, 0, 0), 20); // Red
  colorWipe(strip.Color(0, 0, 255), 20); // Blue
  rainbow(10);
  rainbowCycle(10);
  theaterChase(strip.Color(255, 0, 0), 20); // Red
  theaterChase(strip.Color(0, 255, 0), 20); // Green
  theaterChase(strip.Color(0, 0, 255), 20); // Blue
  theaterChaseRainbow(10);
  whiteOverRainbow(20,75,5);  
  pulseWhite(5); 
  my_delay(250);
  fullWhite();
  my_delay(250);
  rainbowFade2White(3,3,1);
#endif
}

// Fill the dots one after the other with a color
void colorWipe(uint32_t c, uint8_t wait) 
{
  for(uint16_t i=0; i<strip.numPixels(); i++) 
  {
      strip.setPixelColor(i, c);
      strip.show();
      my_delay(wait);
  }
}

void rainbow(uint8_t wait) {
  uint16_t i, j;

  for(j=0; j<256; j++) {
    for(i=0; i<strip.numPixels(); i++) 
  {
      strip.setPixelColor(i, Wheel((i+j) & 255));
    }
    strip.show();
    my_delay(wait);
  }
}



// Slightly different, this makes the rainbow equally distributed throughout
void rainbowCycle(uint8_t wait) 
{
  uint16_t i, j;

  for(j=0; j<256*5; j++) 
  { // 5 cycles of all colors on wheel
    for(i=0; i< strip.numPixels(); i++) 
  {
      strip.setPixelColor(i, Wheel(((i * 256 / strip.numPixels()) + j) & 255));
    }
    strip.show();
    my_delay(wait);
  }
}

// Input a value 0 to 255 to get a color value.
// The colours are a transition r - g - b - back to r.
uint32_t Wheel(byte WheelPos) 
{
  if(WheelPos < 85) 
  {
    return strip.Color(WheelPos * 3, 255 - WheelPos * 3, 0);
  } 
  else 
  {
    if(WheelPos < 170) 
    {
     WheelPos -= 85;
     return strip.Color(255 - WheelPos * 3, 0, WheelPos * 3);
    } 
    else 
    {
     WheelPos -= 170;
     return strip.Color(0, WheelPos * 3, 255 - WheelPos * 3);
    }
  }
}

//Theatre-style crawling lights.
void theaterChase(uint32_t c, uint8_t wait) {
  for (int j=0; j<10; j++) {  //do 10 cycles of chasing
    for (int q=0; q < 3; q++) {
      for (uint16_t i=0; i < strip.numPixels(); i=i+3) {
        strip.setPixelColor(i+q, c);    //turn every third pixel on
      }
      strip.show();

      my_delay(wait);

      for (uint16_t i=0; i < strip.numPixels(); i=i+3) {
        strip.setPixelColor(i+q, 0);        //turn every third pixel off
      }
    }
  }
}

//Theatre-style crawling lights with rainbow effect
void theaterChaseRainbow(uint8_t wait) {
  for (int j=0; j < 256; j++) {     // cycle all 256 colors in the wheel
    for (int q=0; q < 3; q++) {
      for (uint16_t i=0; i < strip.numPixels(); i=i+3) {
        strip.setPixelColor(i+q, Wheel( (i+j) % 255));    //turn every third pixel on
      }
      strip.show();

      my_delay(wait);

      for (uint16_t i=0; i < strip.numPixels(); i=i+3) {
        strip.setPixelColor(i+q, 0);        //turn every third pixel off
      }
    }
  }
}
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

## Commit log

2018-10-01 First Commit! Includes relevant PCB files and source files. WS2812B_test and stylus_keypad_test work. Pot_test was for prototyping board with pots and it worked too. Stylish.pde used to work and no l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
    [Stylish-Belt-Synth - Full.kicad_pcb, Stylish-Belt-Synth - Full.sch, Stylish-Belt-Synth - Left.kicad_pcb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]
2018-10-01 Keyboard with debouncing routines and key up and key down callback functions. Note that distinction between buttons and keys has been eliminated; that should happen outside of the keyboard loop. Not 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
    [Stylish.pde]
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2018-10-07 1st draft of case. Updates to PCB for battery holder mounting and other stuff. Gerbers added for Tindie. Updates to source code, although I don't know if they are the in progress state machine update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
    [Back.stl, Front.stl, SpeakerHolder.stl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]
2018-10-11 Schematic updated with USB and diodes for MODE button. Source code updated with state machine in process.
    [Stylish-Belt-Synth - Full.sch]
2018-10-17 New power switch. 3d model included. 3d model of the amp board included. PCB redesign in progress.
    [MSS22D18 Switch v3.step, Stylish-Belt-Synth - Full.kicad_pcb, Stylish-Belt-Synth - Full.sch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]
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2018-10-17 V0.2 PCB completed! Schematic, PCB, and Gerbers updated.
    [Stylish-Belt-Synth - Full-B.Mask.gbr, Stylish-Belt-Synth - Full-B.Paste.gbr, Stylish-Belt-Synth - Full-B.SilkS.gbr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]
2018-10-23 PCB tweaked a little. Zig zag cut line generated on User 1 layer. Souce code: state machine in progress.
    [Stylish-Belt-Synth - Full.kicad_pcb]
2018-11-03 More work on state machine source. 3d models for 3d printing added
    [Amp Cover.stl, Belt Clip.stl, Front v2.stl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]
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2019-03-18 Updated PCB to have contiguous outline. Yet another incomplete reworking of the state machine.
    [Stylish-Belt-Synth - Full.kicad_pcb]
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2019-06-25 More board cleanup. Fixed values of parts based on test board construction. Rewired potentiometer so that low volume is nearest the power on/off click. More hand vias where they are needed.
    [Stylish-Belt-Synth - Full.kicad_pcb, Stylish-Belt-Synth - Full.sch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]
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2019-07-08 Top Fixture
    [StylishWoodFrontFixtureCNC.stl]
2019-07-11 Small updates to PCB. One footprint changed so all SMD are 0805. BOM added. V1 of Source Code added.
    [Stylish-Belt-Synth - Full.csv, Stylish-Belt-Synth - Full.kicad_pcb, Stylish-Belt-Synth - Full.ods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]
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2019-07-12 Step files for V2 and V4 for Bruce
    [Stylish Belt Synth V2 LED Lightpipe.step, Stylish Belt Synth V2 Left Battery Door.step, Stylish Belt Synth V2 Right Battery Door.step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]
2019-07-13 Updated PCB to have heat dissipation for the amplifier chip. Risky last minute changes...
    [Stylish-Belt-Synth - Full-B_Cu.gbl, Stylish-Belt-Synth - Full-B_Mask.gbs, Stylish-Belt-Synth - Full-B_SilkS.gbo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]
2019-07-13 Changed LED ring resistor from 44Ω to 30Ω.
    [Stylish-Belt-Synth - Full-B_Cu.gbl, Stylish-Belt-Synth - Full-B_Mask.gbs, Stylish-Belt-Synth - Full-B_SilkS.gbo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]
2019-07-13 Updated BOM with new speaker, and lower value LED ring resistor.
    [Stylish-Belt-Synth - Full.csv, Stylish-Belt-Synth - Full.ods, Stylish-Belt-Synth - Full.xlsx]
2019-07-13 Delete Stylish-Belt-Synth - Full-Edge_Cuts.gbr
    Went to protel extensions
    [Stylish-Belt-Synth - Full-Edge_Cuts.gbr]
2019-07-13 Delete Stylish-Belt-Synth - Full-F_Cu.gbr
    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
    [Stylish-Belt-Synth - Full-F_Cu.gbr]
2019-07-13 Delete Stylish-Belt-Synth - Full-B_Cu.gbr
    went to protel extensions
    [Stylish-Belt-Synth - Full-B_Cu.gbr]
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2019-07-14 Moved silkscreen for U2 to not be under the chip where we need connection to the ground plane. Updated Gerbers to match. Updated 3d renders for texture map.
    [Stylish-Belt-Synth - Full-B_Cu.gbl, Stylish-Belt-Synth - Full-B_Mask.gbs, Stylish-Belt-Synth - Full-B_SilkS.gbo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]
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2019-07-19 Added inner plastic lip to plastic V4 model. Finished PCB supports. PCB now screws into the top. TODO: Add screw holes to the edges, Battery compartments.
    [Stylish Belt Synth V4 Plastic Enclosure Bottom.step, Stylish Belt Synth V4 Plastic Enclosure Lightpipe.step]
2019-07-30 Wood CNC integrated into one file, updated to 8.5 to get around bug. LED code updated to show white first as the best test for LEDs. Keyboard code updated to test buttons correctly.
    [WS2812B_test.ino, stylus_keypad_test.ino]
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2019-07-31 3d models updated to proper clearances. Aspire files in progress.
    [StylishWoodBackFixtureCNC.stl, StylishWoodFrontFixtureCNC.stl]
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2019-08-04 Update all Wood CNC models, Aspire, and gcode
    [Stylish Belt Synth CNC Wood Bottom Interior.dxf, Stylish LED BezelForWood.stl, StylishLEDLightpipeForWoodCNC (3d print this).stl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]
2019-08-07 Model updates for fixed lightpipe cutout. Aspire update for fixed lightpipe cutout. Gcode update for 1 inch top wood thickness.
    [Stylish Belt Synth CNC Wood Top Interior.dxf, Stylish LED BezelForWood.stl, StylishLEDLightpipeForWoodCNC (3d print this).stl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]
2019-08-12 Updated Fixtures. Volume wheel model for 3d print
    [Stylish Volume Wheel (3d print).stl, StylishWoodBackFixtureCNC.stl, StylishWoodFrontFixtureCNC.stl]
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2019-09-03 Updated Shark CNC Aspire and g-code files. Batch file for combining the g-code added. Work on the real synth source code: bit packing for patch storage complete. button detection fixed.
    [Stylish.pde]
2019-09-09 Noise and Envelope. Some default sound data. Write and restore patches kinda works.
    [Stylish.pde]
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2019-09-11 All synth parameters implemented except PWM and env to noise (which might be useless). Patches now save correctly to Flash!
    [Stylish.pde]
2019-10-15 Finally! The plastic case V4 for the "final" PCB! Works with the volume control and all jacks! Haven't tested it yet!
    [Stylish Belt Synth V4 Battery Door 1.stl, Stylish Belt Synth V4 Battery Door 2.stl, Stylish Belt Synth V4 LED Bezel.stl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]
2019-10-15 STEP files of "final" plastic case for V4 PCB.
    [Stylish Belt Synth V4 Battery Door 1.step, Stylish Belt Synth V4 Battery Door 2.step, Stylish Belt Synth V4 LED Bezel.step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]
2019-10-18 Fixed tuning in source code. Allow for patch reset by holding down patch select button on power on. Mode parameters: LED bright (C0) Coarse Pitch (C#0) Fine Pitch (D0) Updates to battery door models 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
    [Stylish Belt Synth V4 Battery Door 1.stl, Stylish Belt Synth V4 Battery Door 2.stl, StylishVolumeWheelforWoodCNC (3d print this).stl]
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2019-11-03 Trimmed tabs on the battery doors for a better fit. Hopefullt I didn't make them too small.
    [Stylish Belt Synth V4 Battery Door 1.step, Stylish Belt Synth V4 Battery Door 1.stl, Stylish Belt Synth V4 Battery Door 2.step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]
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2020-02-13 Top Negatives, walls for battery door molds, thin battery doors
    [Stylish Belt Synth - Battery Doors - Outside Positive Walls.step, Stylish Belt Synth - Battery Doors - Outside Positive Walls.stl, Stylish Belt Synth - Right B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]
2020-03-12 Moved and renamed files to new directory structure, this time using "git mv". Added in the models for LED Bezels and Lightpipes.
    [Stylish - Top - Outside Positive.stl, Stylish - Top Outer Mold Mold.stl, Stylish Belt Synth - Battery Door 1 - Inside Negative.step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]
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2020-03-12 Fix windows non-case sensitivity / GIT *UX case sensitivity error in OLD / old directory.
    [Stylish Belt Synth V2 Left Battery Door.stl, Stylish Belt Synth V2 Right Battery Door.stl]
2020-03-14 Hollow versions of mold molds for SLA printing. LED Lightpipe Outside Positive.
    [Stylish Belt Synth - LED Lightpipe - Outside Positive.stl]
2020-03-19 Adding hollow STL parts for mold molds to conserve material. Also mold walls for LED bezel. Saved a STEP version of the LED Bezel, because my Fusion startup license expired and they haven't renewed i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
    [Stylish Belt Synth - LED Bezel - Mold Walls.step, Stylish Belt Synth - LED Bezel - Mold Walls.stl]
2020-05-11 Updated hollow mold molds to be thicker / more printable (maybe?). Updated Shark CNC gcode to put the jumper slot back in. Added binary files of built source code for direct uploading.
    [Stylish Belt Synth - Battery Doors - Outside Positive Walls.step, Stylish Belt Synth - Battery Doors - Outside Positive Walls.stl, Stylish Belt Synth - LED Bez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]
2023-05-01 Updated files to latest KiCad Added PDF and SVG versions of schematics Added PDF for PCB front and back reference Added photos of completed units and pcbs
    [MAG Synth.kicad_pcb, MAG Synth.sch]
2023-11-15 Added cache.lib, hopefully that solves missing footprints.
